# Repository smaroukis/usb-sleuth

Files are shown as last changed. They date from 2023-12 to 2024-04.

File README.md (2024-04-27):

See [this README](/README-downloading-firmware.md) for usage of the STM32CubeIDE to flash firmware on the device. 

## Overview

The device tests for continuity and internal resistors within various USB Cables and exposes some pins for multimeter testing. The project is a hardware fork of [aroerina/LimePulse](https://github.com/aroerina/LimePulse_USB_cable_checker/) that I decided to reverse engineer and write the firmware for.

A STM32C031K6T microcontroller is used for testing connection and orientation, powered by a CR2032 battery. Code is given using STM32 HAL libraries and the device can being programmed over SWD. 

KiCad and gerber files are provided for the board layout, as well as the library footprints for non-standard parts ordered from JLCPCB/LCSC. 
See the [BOM](/production/38-04-usb-tester_2023-12-18_rev1/bom.csv).

This USB cable tester has the "B" side on the right, and the "A" side on the left. Receptacles are given for the following:
- Type-C (both sides) 
- Type-C to A 
- Type-C to micro B (2.0)
- Type-C to mini B 

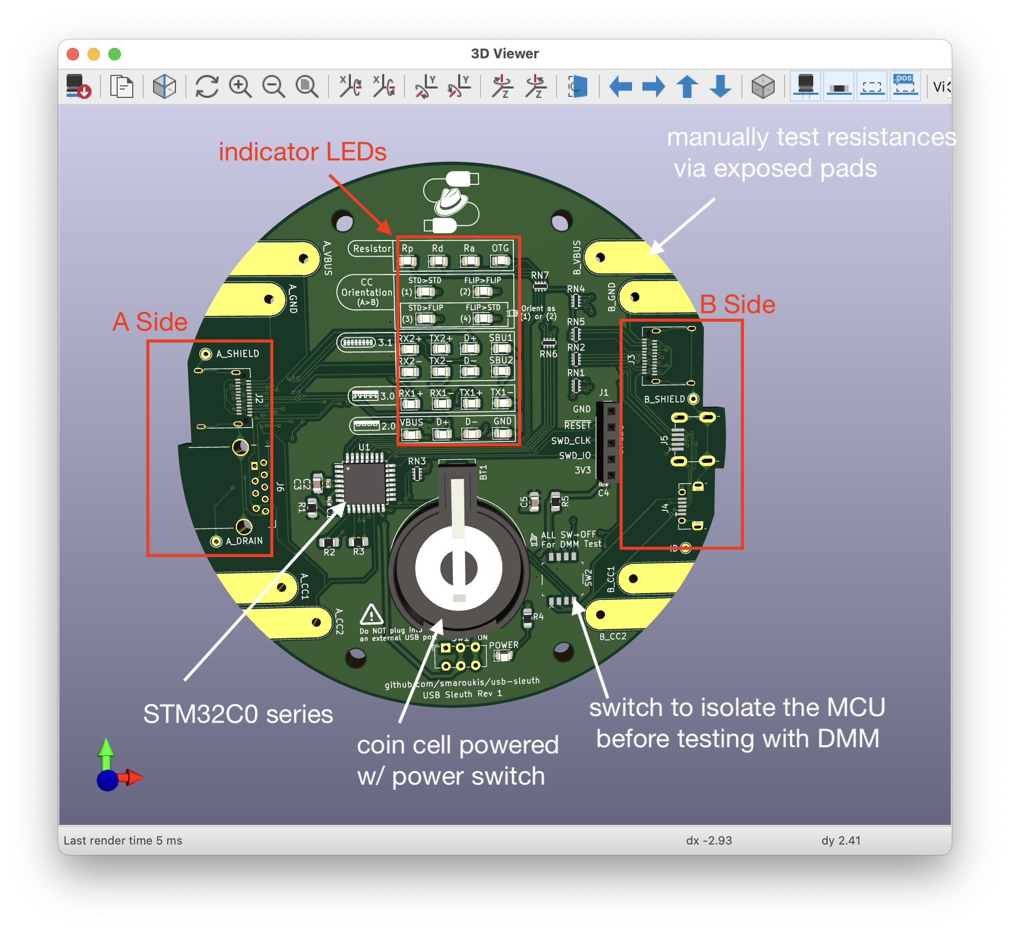
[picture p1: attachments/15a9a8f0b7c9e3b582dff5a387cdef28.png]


The device has some benefits over a simple continuity tester
- displays the as-plugged orientation of the 4 different possibilities of the USB-C to C cable
- detects pullup and pulldown resistors on the CC lines as required by the USB standard for legacy cables 
- identifies active cable with E marker (via the pulldown resistor present on VCONN)
- doesn't apply a +V to the Ground line/pin, instead it uses a MCU to test the presence of a connected ground wire
- exposes various pins to test cable and internal resistors manually with a DMM

## Example Tests

#### USB C-C Active Cable
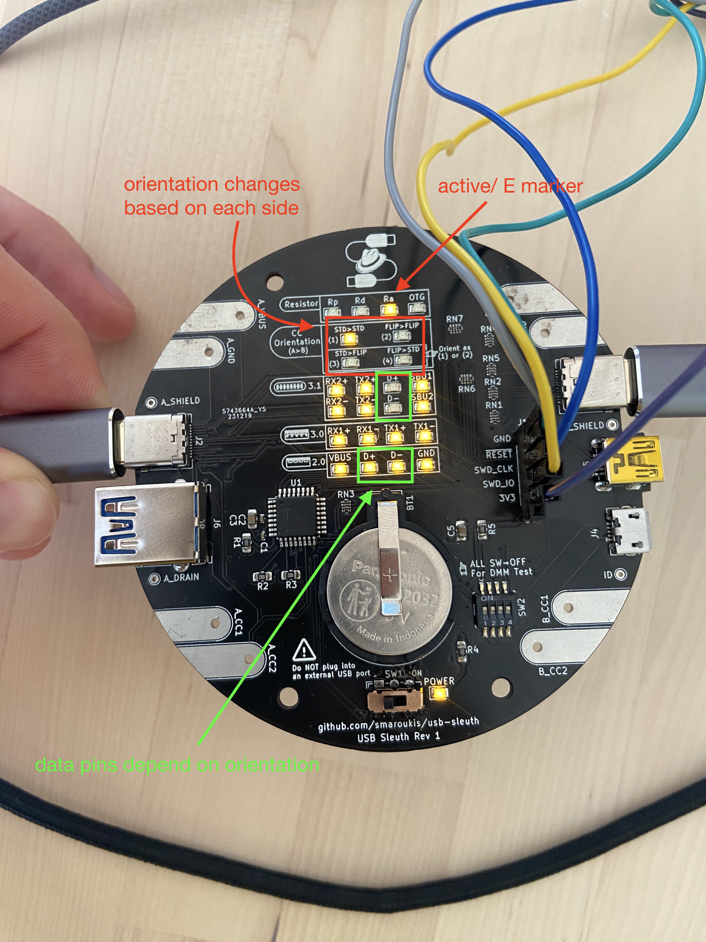
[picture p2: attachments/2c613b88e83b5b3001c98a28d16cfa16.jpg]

> Note in this test only one of the USB 2.0 Data pair LEDs will light up depending on the cable orientation, showing that the two pairs are not connected inside the cable (the pairs are also not connected on the PCB). The user must flip the orientation to test both data pairs. 
#### DMM Test of Internal Resistor

Testing the value of the pulldown resistor on an active cable by measuring between `B_CC2` and `B_GND` (should be between 800-1.2K Ohms).
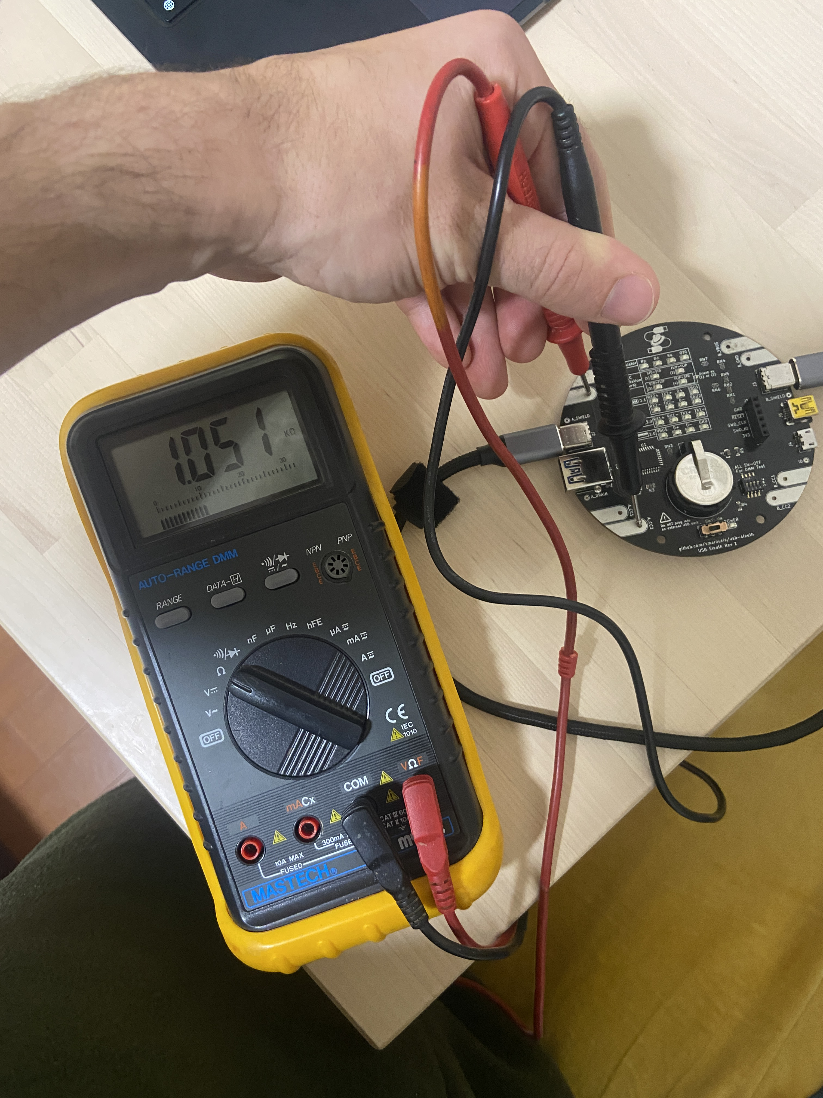
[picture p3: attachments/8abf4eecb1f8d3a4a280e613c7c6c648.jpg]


#### OTG Test

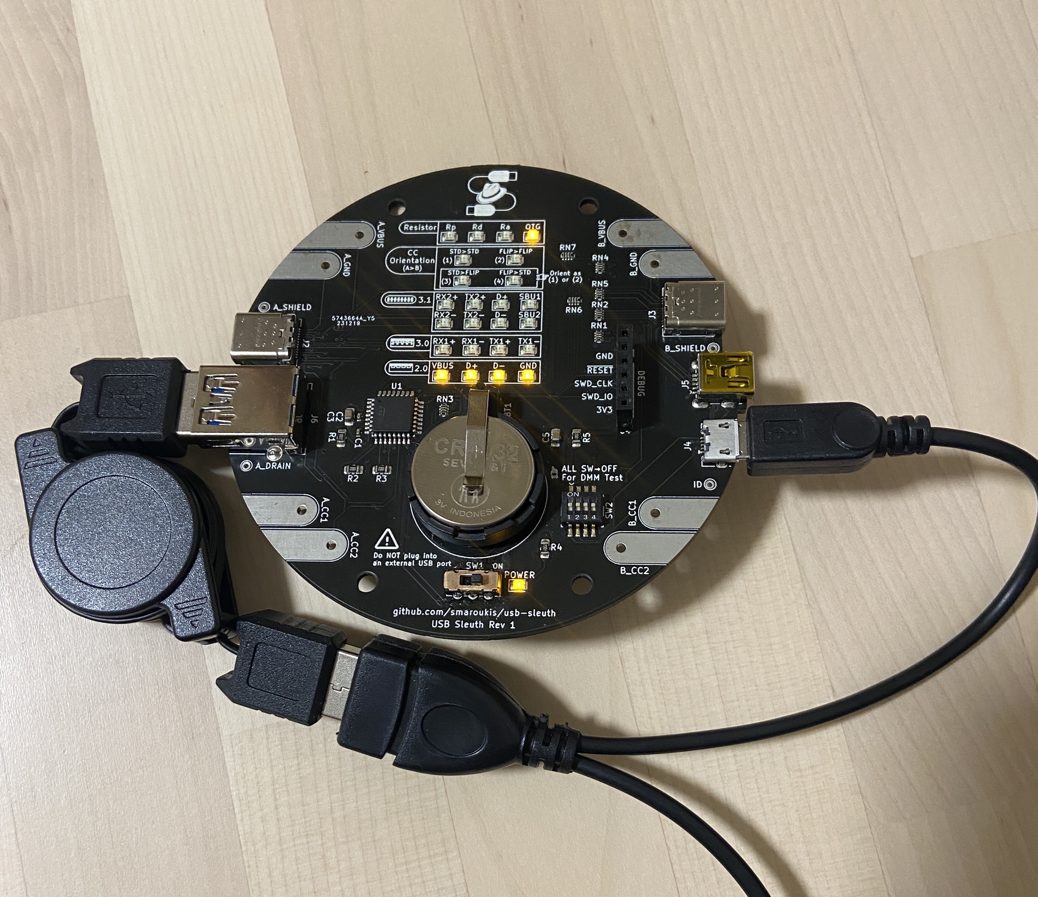
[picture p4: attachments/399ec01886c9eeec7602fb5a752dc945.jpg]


## General PCB Layout

Layout
- Various B side pins are biased to VBUS through pullup resistors. A side pins are either connected to ground through an LED, thus lighting up if the corresponding wire is continuous, or the pins are connected into the MCU for inputs. These pins that the MCU tests for are as follows:
- Ground (note all four GND pins are tied together)
- VBUS (note all four VBUS pins are tied together)
- CC1 to test for CC line and orientation
- CC2 to test for VCONN line and pull down resistor for active cables, as well as a flipped CC cable

> Note: Both A-side and B-side CC1 and CC2 pins are tapped off into corresponding control inputs to the MCU through a resistor, allowing for pulling the control pins high or low to sense the result on the opposite side.

Simplified layout of testing CC1 pin.
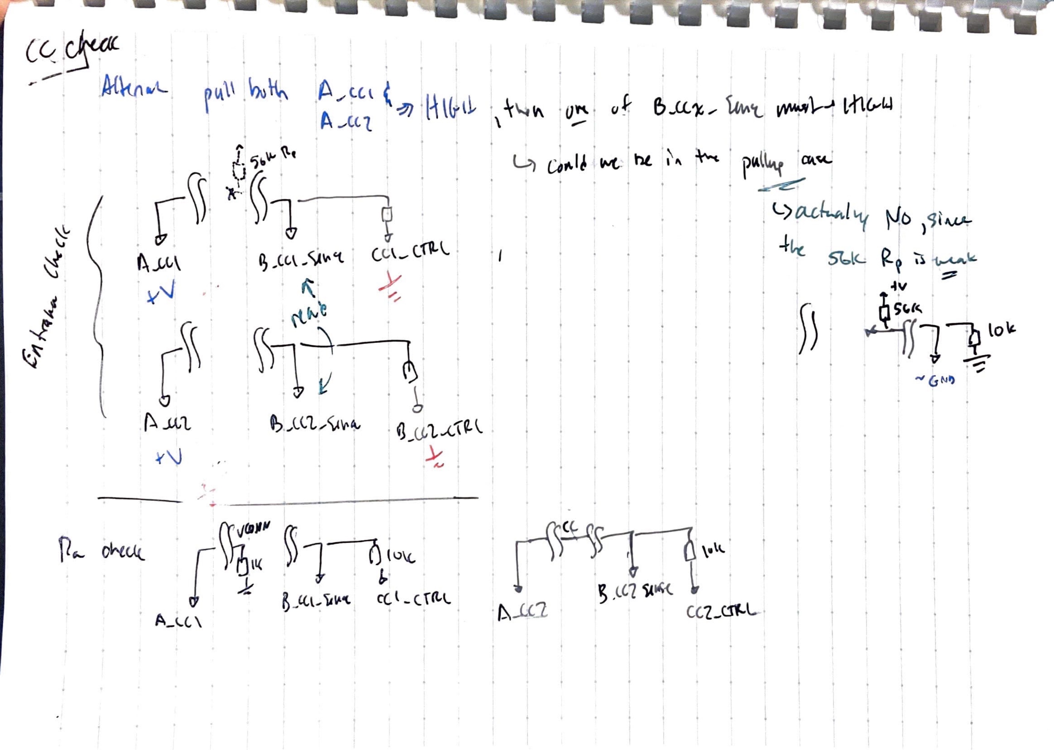
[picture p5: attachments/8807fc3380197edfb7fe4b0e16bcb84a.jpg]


## Programming and Reset

Programming is done via the Serial Wire Debug headers (labeled `DEBUG`) via an STLink debugger probe. 

The device can also be reset by shorting out the `nRESET` line to `GND` (pins 1 and 2 on the header).

> [!CAUTION]
> In the case where the debugger is providing power to the target, make sure the `POWER` switch is `OFF`.

> [!NOTE]
> For the `SWD` pins we need pullup or pulldown resistors on `SWDIO` and `SDCLK` respectively. These are provided internally by the STM32 MCU, but if there is an issue with the debugger try adding an external weak pulllup and pulldown (10K-100K).

# Description of Operation

## Sensing VBUS and GND 

> [!NOTE]
> `VBUS`: Pulled up on B-side to VDD via 2K, pulled down to ground at A-side MCU input sense pin via 10K. Sense pin reads high if VBUS line is continuous through the cable.
> `GND`: B-side receptacle ground pin connected to board ground, A-side receptacle pin is direct to input sense pin.

All VBUS pins are tied together and tested via a pulldown resistor on the MCU (similarly for GND pins).

Most B-side receptacle pins are pulled up to supply/VDD through resistors with exception for CC pins and Ground. B-side ground is connected to board ground through a DIP switch for isolation from the MCU ground if needed.
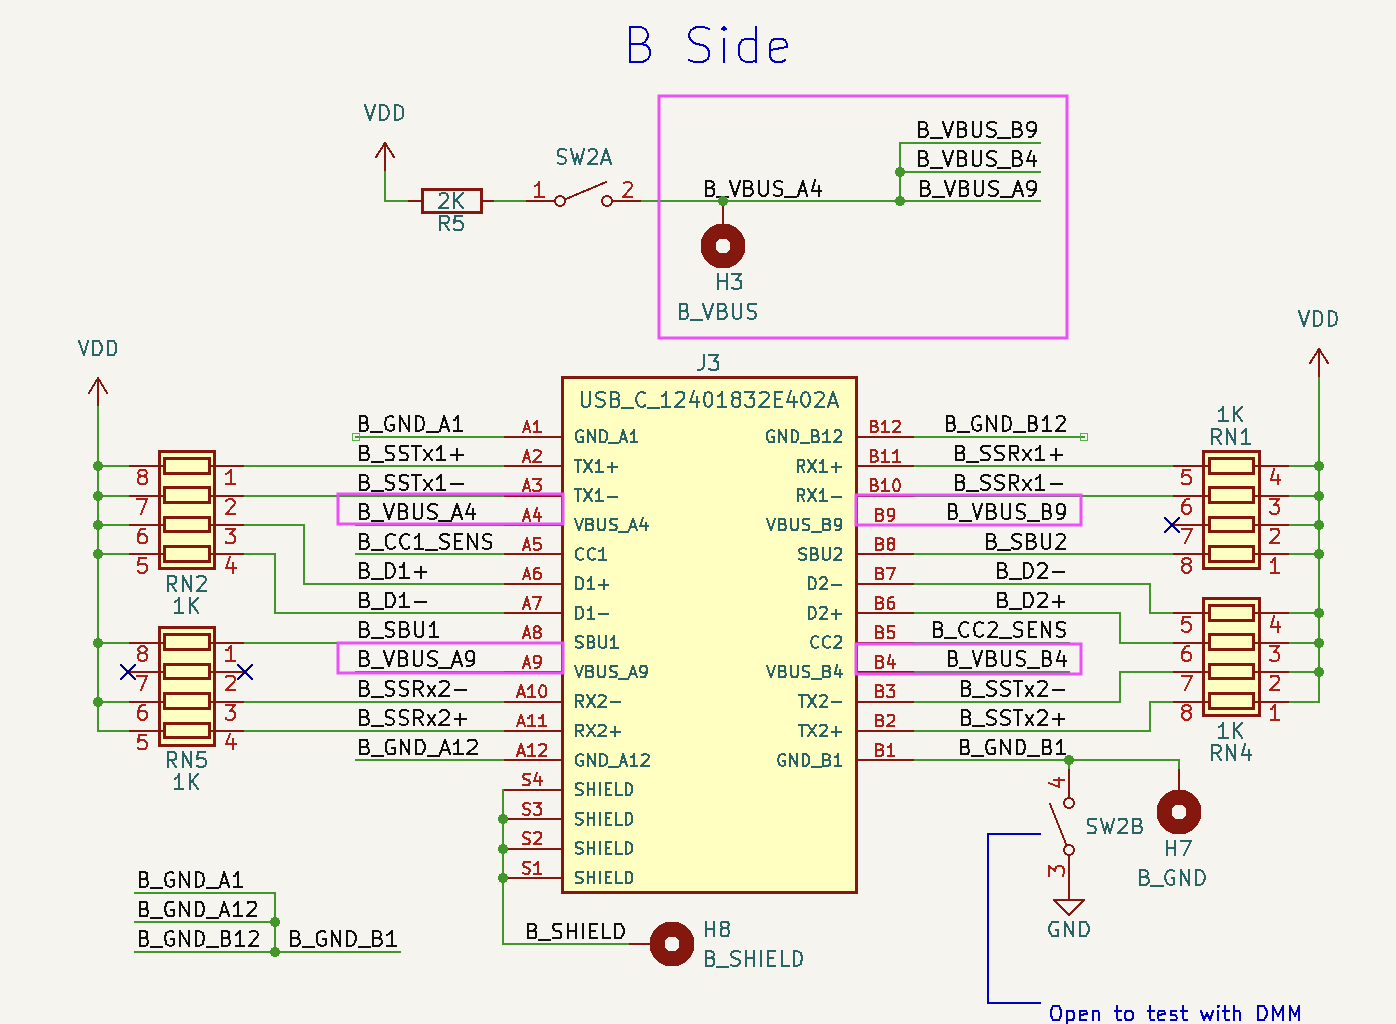
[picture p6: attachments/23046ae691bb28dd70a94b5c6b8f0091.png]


A-side receptacle pins are connected to the MCU input for sensing.
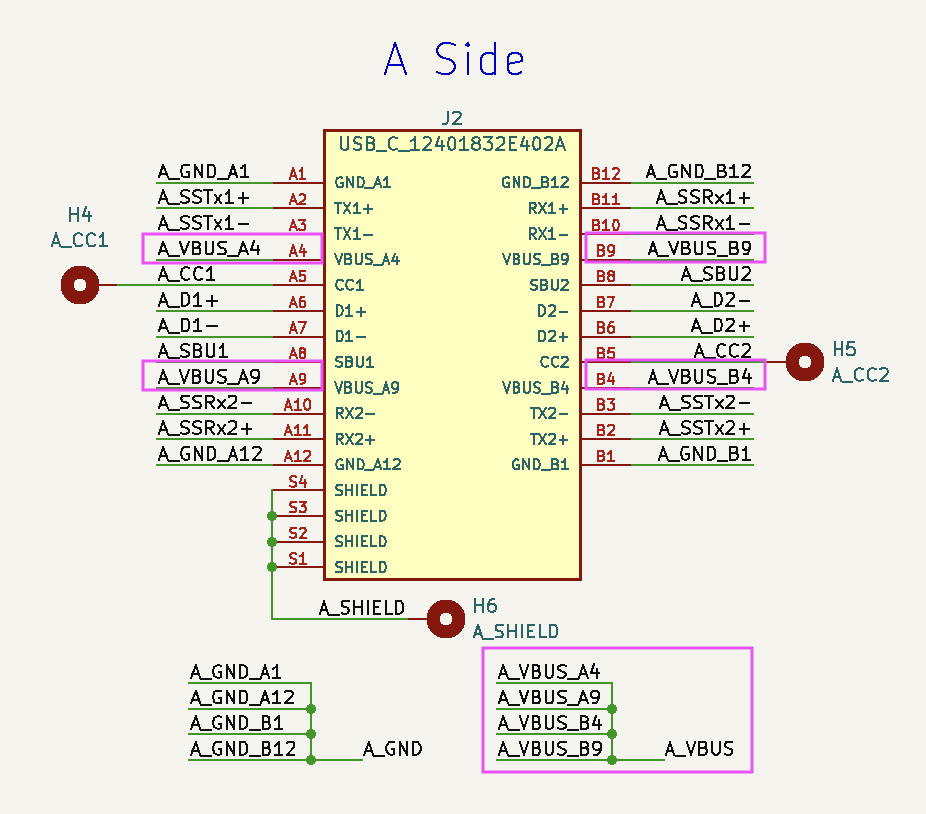
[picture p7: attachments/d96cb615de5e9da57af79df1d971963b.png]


`A_VBUS`/`A_GND` and connected to `VBUS_SENSE`/`GND_SENSE` inputs to the MCU through DIP switches for isolation from the MCU during DMM testing.

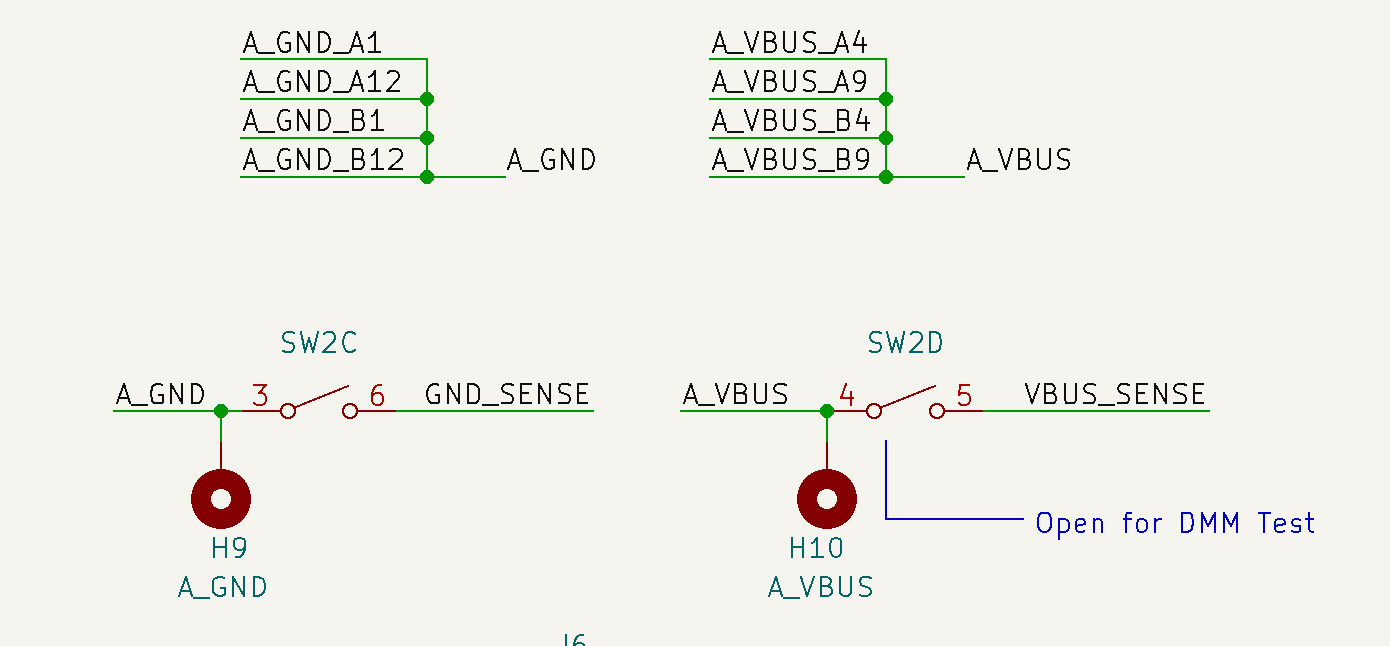
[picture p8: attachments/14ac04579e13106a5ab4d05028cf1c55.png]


`VBUS_SENSE` pin is an input to the MCU with a pull down resistor forming a voltage divider with the 2K VDD pulllup resistor. If the `VBUS` line is discontinuous, the pin reads `LOW`. If `VBUS` is continuous then the pin reads `VCC`x10/12, or digital `HIGH`. 

Indicator LEDs are driven by the MCU outputs `GND_LED` and `VBUS_LED`.

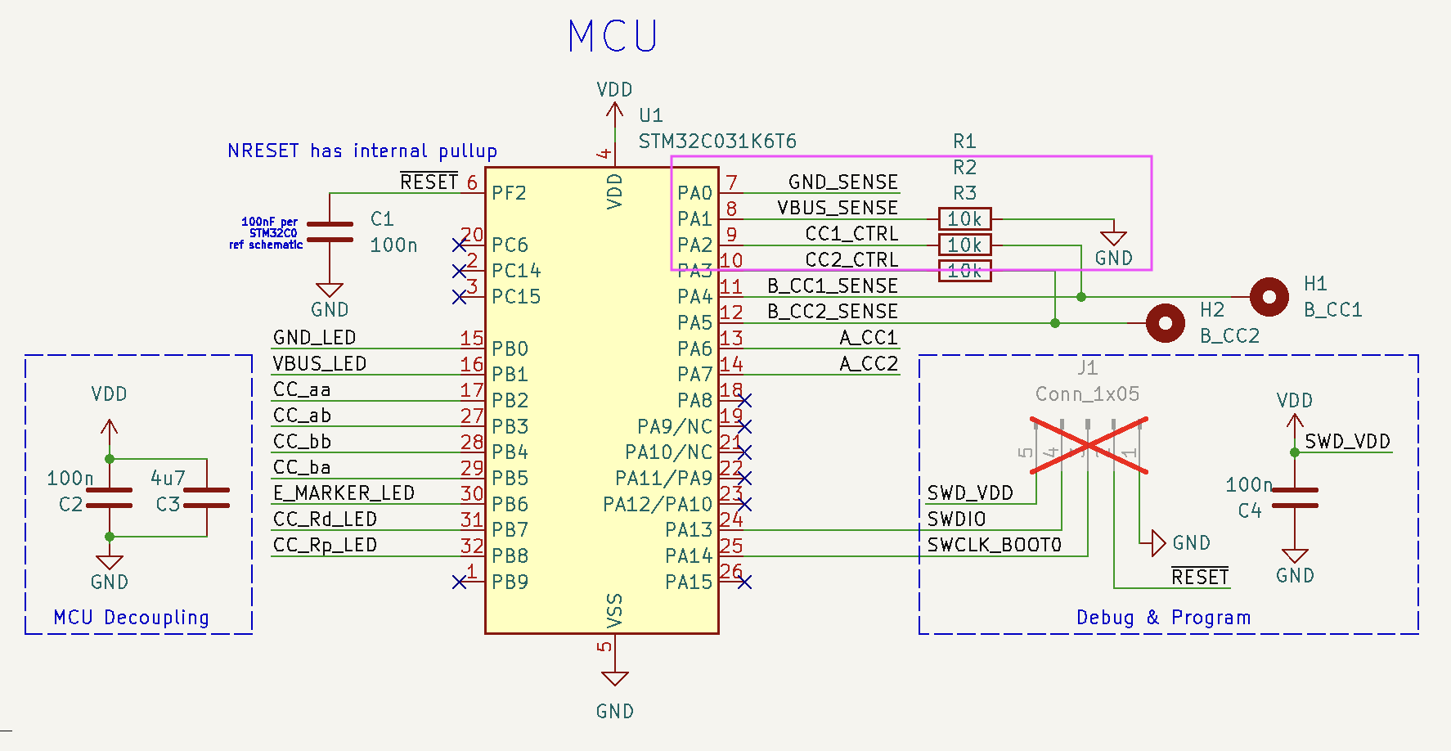
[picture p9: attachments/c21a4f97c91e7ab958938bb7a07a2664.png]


# MCU Testing Logic

### Orientation of CC Pin

Here is the type-C receptacle pinout 
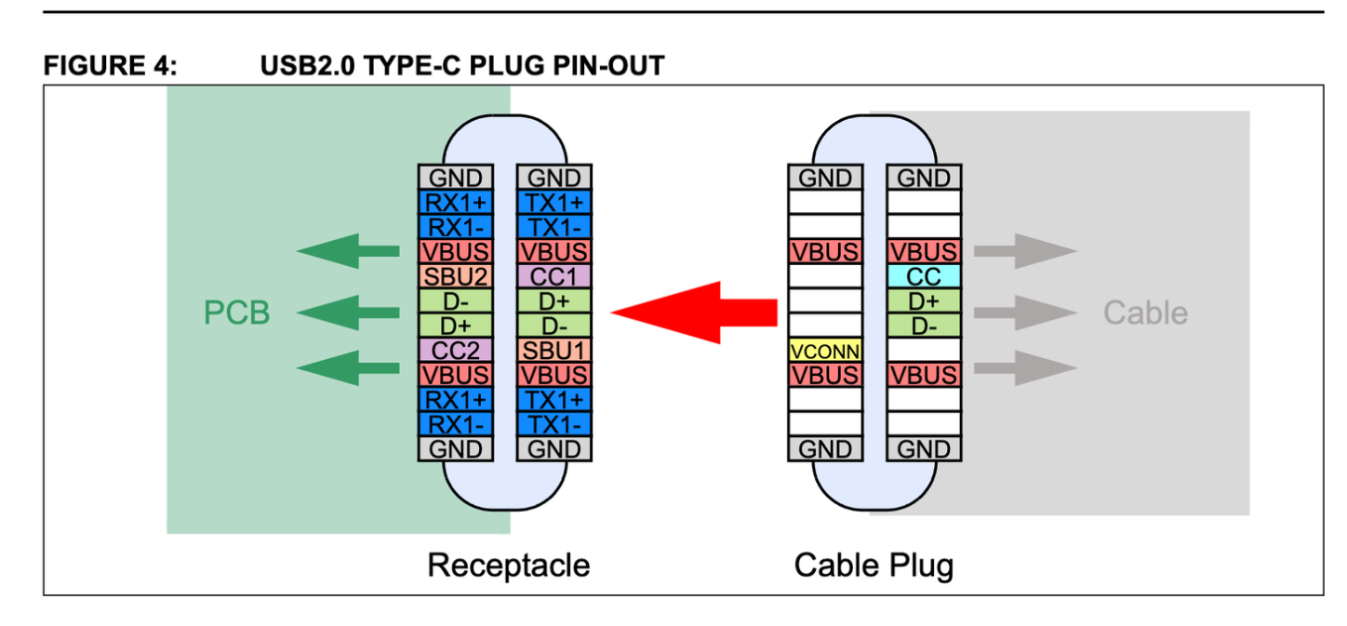
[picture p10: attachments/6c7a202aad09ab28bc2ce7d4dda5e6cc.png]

> Source: "USB 2.0 Type-C Plug Pin-Out" https://ww1.microchip.com/downloads/en/appnotes/00001953a.pdf

Possible orientations of USB-C Plug. 
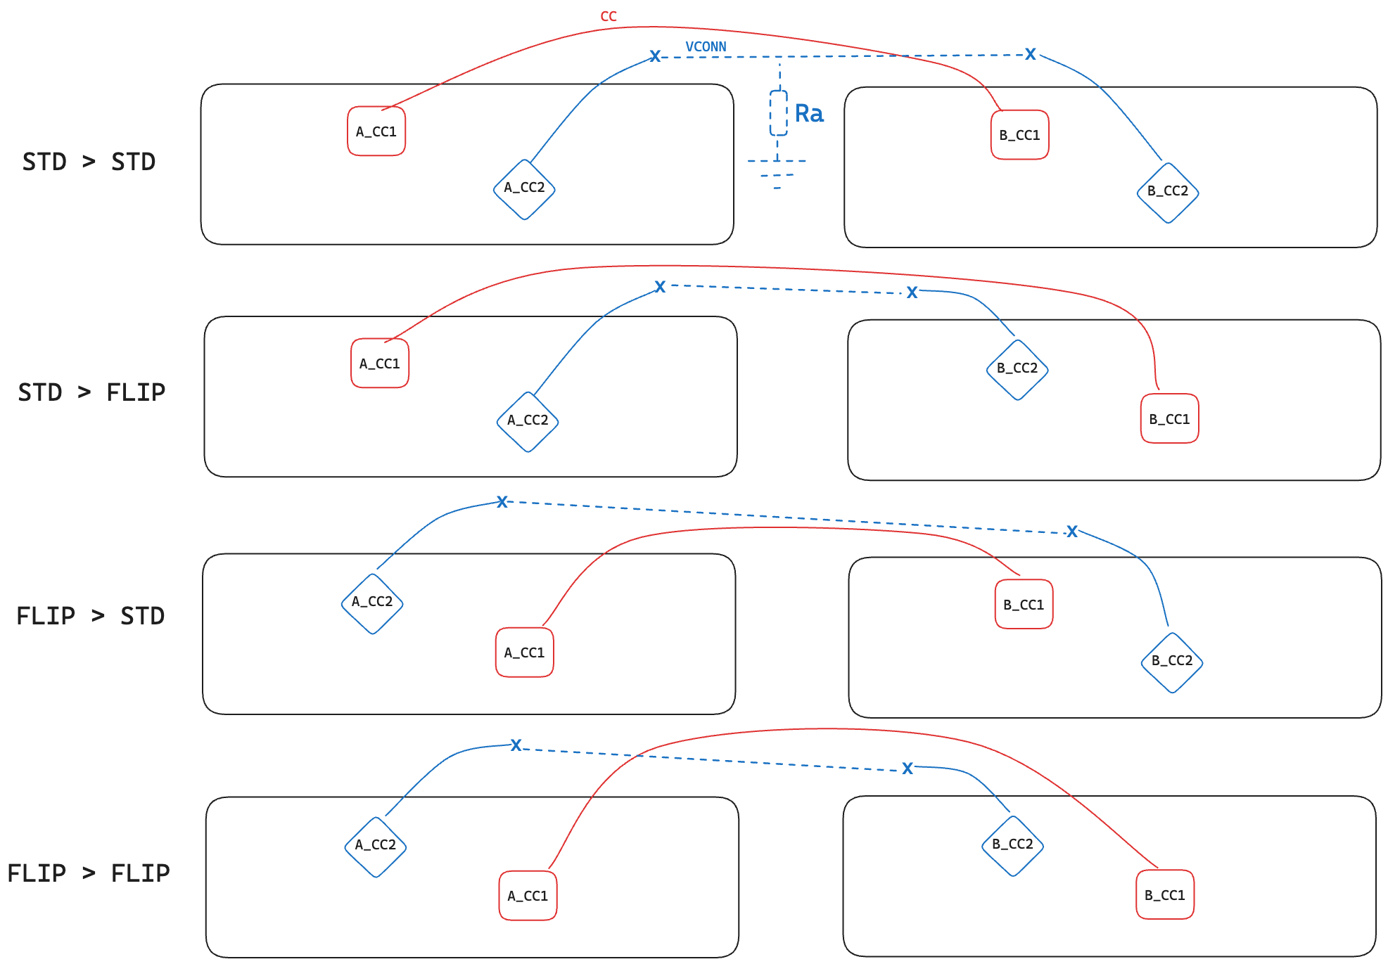
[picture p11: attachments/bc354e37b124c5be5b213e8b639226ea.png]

> Note Ra is for the active pulldown emarker, but don't take this "straight through" configuration literally as there are diodes preventing shorting of the pins.

Simplified PCB layout:


We can determine that a C-C type cable is connected by pulling both A_CC1 and A_CC2 HIGH and CCx_CTRL pins LOW, then looking for one of the B_CCx pins coming HIGH.

### MCU Testing of Ra on Emarker (Active) Cables

The pulldown (Ra, for "active") is nominally 800-1.2K. Connection is as follows:

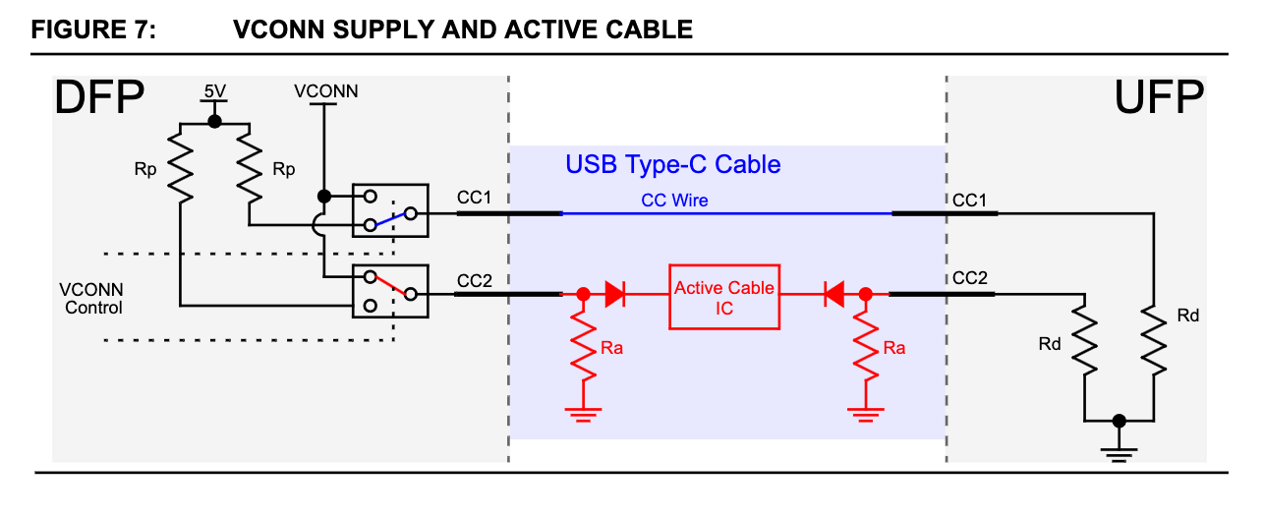
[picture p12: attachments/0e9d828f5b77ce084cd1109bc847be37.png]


We simply configure the `A_CC2` and `B_CC2` pins as `INPUT_PULLUP`s and test if these lines (the `VCONN` line) are pulled low (normally it is open), since the pulldown Ra is strong at ~1K.

## MCU Testing of Rp on Type-A to Type-C Cable

> [!NOTE]
> It is programmed to work for both USB-C plug orientations

Setup
1. `VBUS` is connected to `VCC` through a 2K resistor (ignored for the calculations below)
2. Write `CC1_CTRL` and `CC2_CTRL` → `LOW` (pulls `B_CCx` pin toward ground through 10K R)
3. Perform analog read of `B_CC1_sense` and `B_CC2_SENSE`
4. If the analog read is above a threshold, `RP_THRESH`, to account for ground noise, then the 56K Rp pullup exists. 

> [!TIP]
> An analog read is required since the internal Rp is weak enough such that it doesn't pull it all the way up to the digital `HIGH` threshold

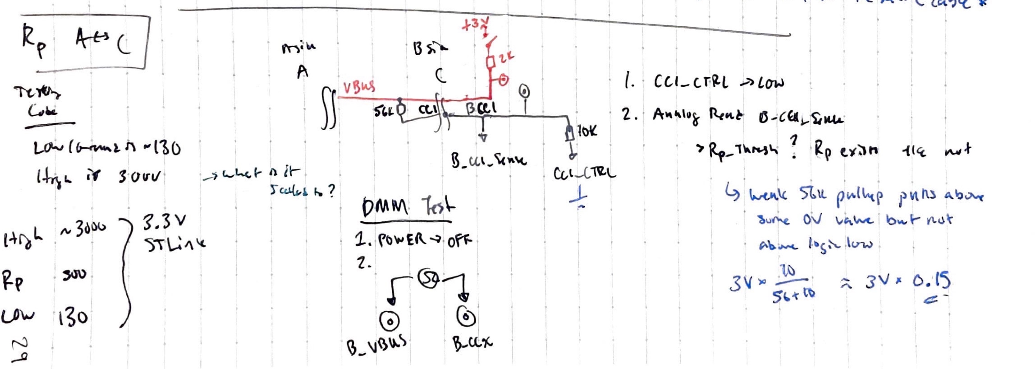
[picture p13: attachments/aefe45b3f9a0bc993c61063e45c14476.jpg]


## MCU Testing of Rd on Type-B to Type-C Cable

> Note this works for both CC configurations

1. Set `A_CC1` as `INPUT_PULLUP` (~50K internal pullup)
2. Read `A_CC1`, if pulled `LOW`, then it means that `Rp` is present (Rd = 5K which is much stronger than the 50K internal pullup)

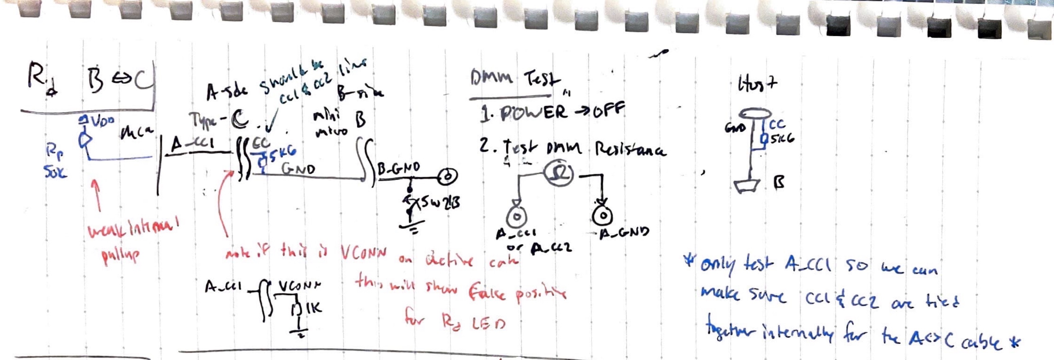
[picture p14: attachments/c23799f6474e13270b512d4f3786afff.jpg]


## Power Isolation For Testing

Isolation switches are provided to isolate the DMM from the MCU as it injects a test current to measure resistance, and also to allow us to measure the resistance of the cable itself (e.g. VBUS to GND). 

> Note during testing it was found that even with the switches closed the DMM measurements weren't affected.  

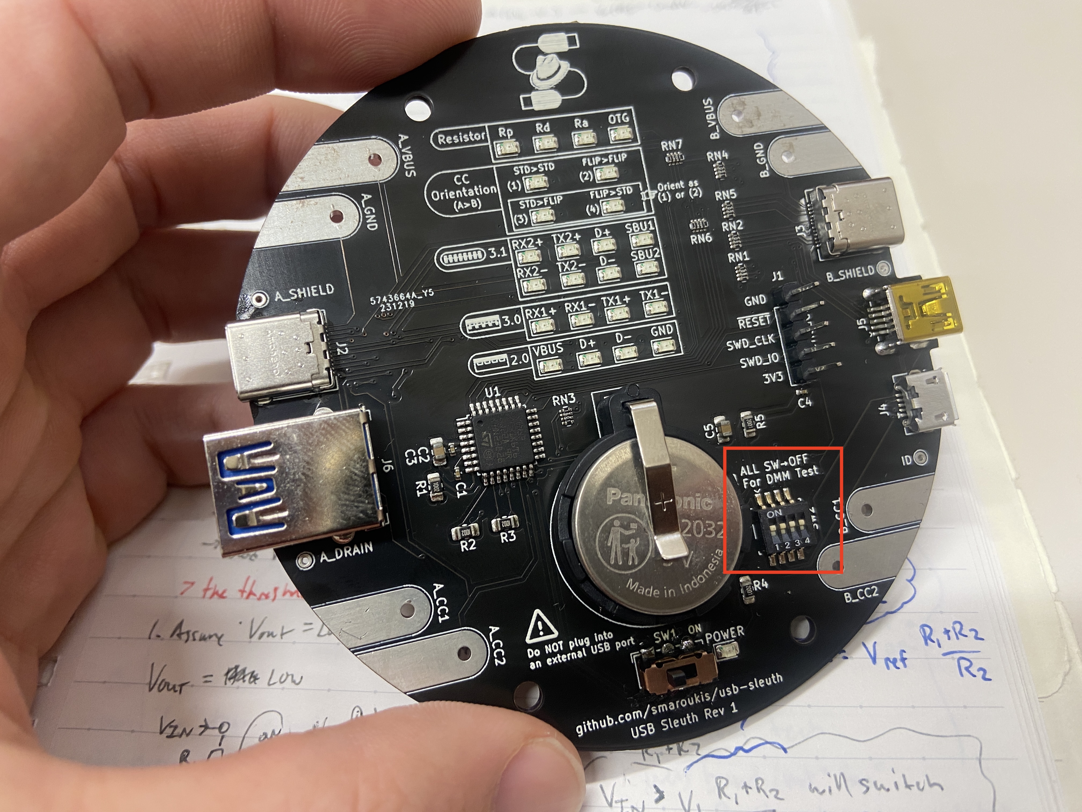
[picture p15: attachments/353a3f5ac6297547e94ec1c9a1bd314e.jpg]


In the schematic these are modeled as a multi-unit DIP switch:
- `SW2A`: Separates `VCC` from `VBUS`
- `SW2B`: Separates `B_GND` from `GND`
- `SW2C`: Separates `A_GND` from `A_GND_SENSE` (input to MCU)
- `SW2D`: Separates `A_VBUS` from `A_VBUS_SENSE` (input to MCU)

# DMM Testing

## DMM Testing of  Rp on CC line

> [!Caution]
> Verify the following:
> 1. USB cable is in the normal CC Orientation of `STD>STD` before proceeding (or note the configuration to choose the correct pad to test)
> 2. All DIP switches are in the OFF position
> 3. Power switch is in the OFF position

For the Type-A to C cable the USB standard specifies at 56K pullup resistor between `VBUS` and `CC` (since the A side is the host, CC pin needs to be pulled up for the B-side/peripheral to recognize A side as host). 

We can test the exact value of this resistor by using a DMM between `B_VBUS` and `B_CC1` testing pads.

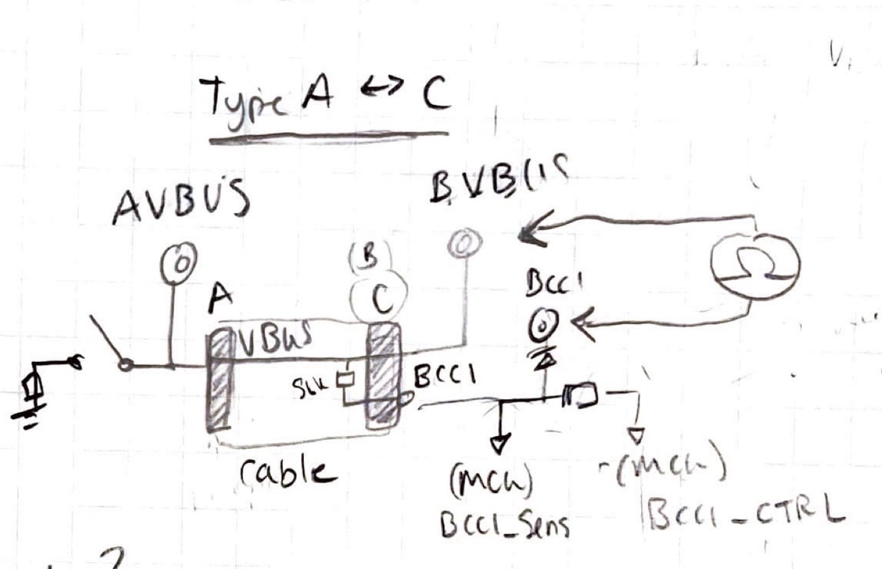
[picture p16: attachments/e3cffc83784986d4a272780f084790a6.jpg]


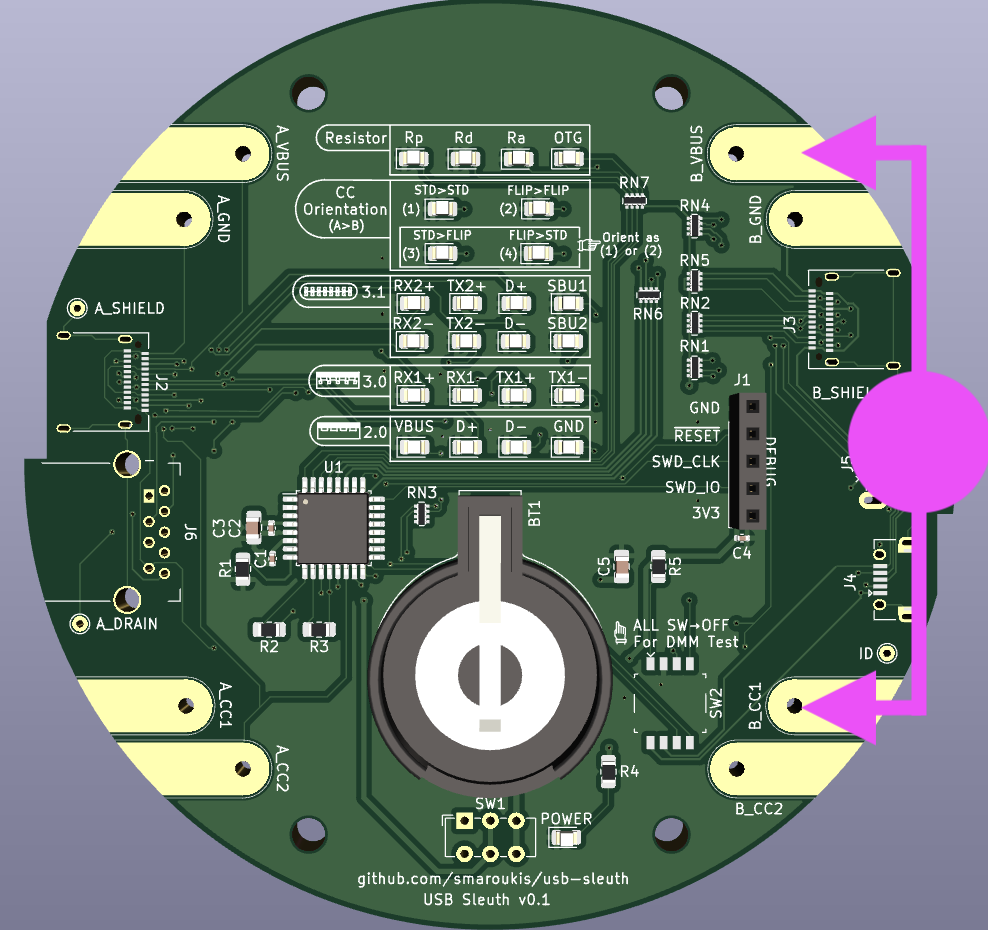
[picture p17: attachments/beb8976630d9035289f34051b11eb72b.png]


## DMM Testing of Rd

> [!Caution]
> Verify the following:
> 1. USB cable is in the normal CC Orientation of `STD>STD` before proceeding (or note the configuration to choose the correct pad to test)
> 2. All DIP switches are in the OFF position
> 3. Power switch is in the OFF position

For the Type-B to C cable the USB standard specifies at 5K6 pulldown resistor between `CC` and `GND` (since the B side is the peripheral, CC pin needs to be pulled down for the A-side/host to recognize B side as peripheral). 

We can test the exact value of this resistor by using a DMM between 
`A_GND` and `A_CC1` 

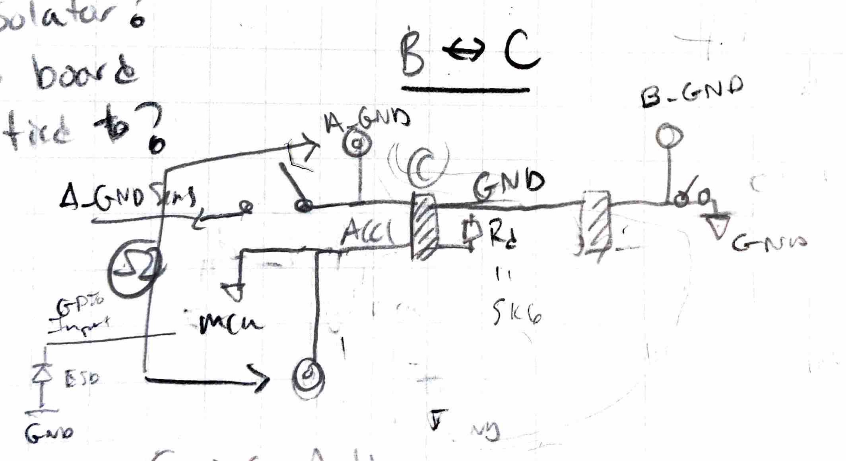
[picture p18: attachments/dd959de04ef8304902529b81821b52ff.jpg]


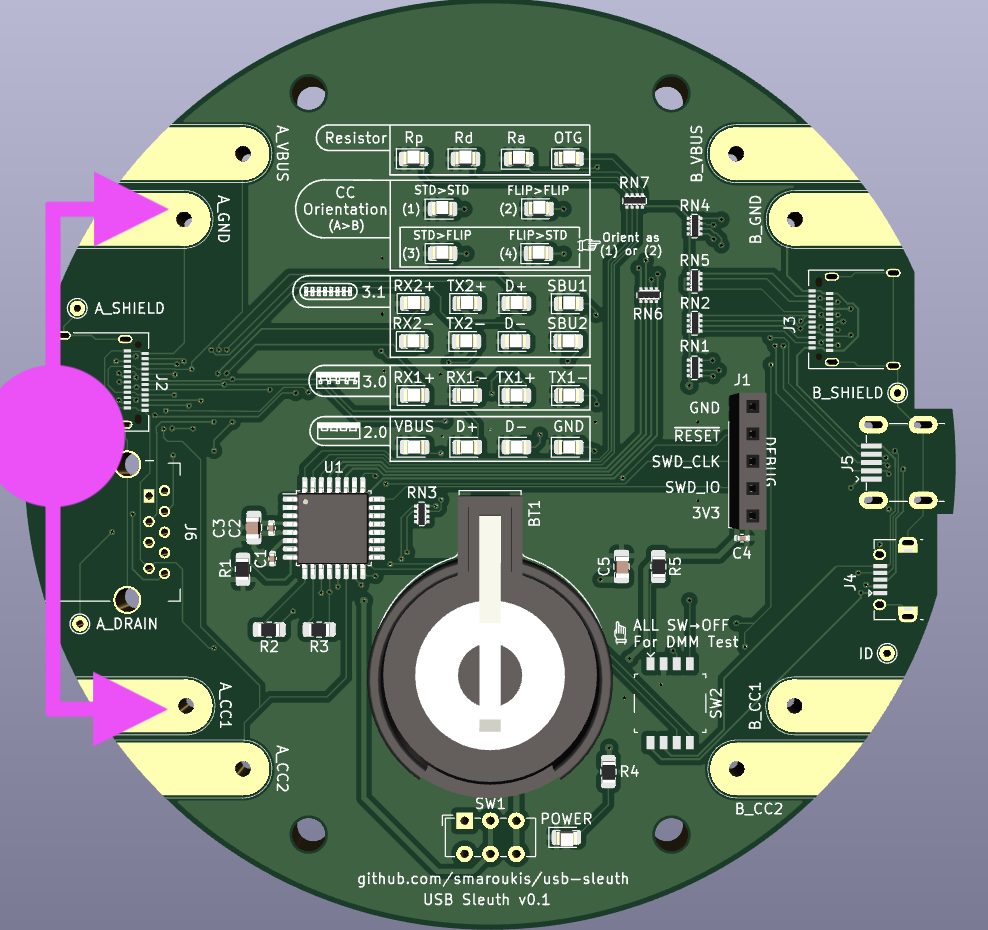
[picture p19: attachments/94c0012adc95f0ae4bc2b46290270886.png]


## DMM Testing of Ra

1. With device ON, make sure the CC orientation is `STD>STD`
2. Switch isolation switches to OFF
3. Switch power OFF
4. Place a DMM between `B_CC2` and `B_GND` since the Ra will be on the VCONN line.

# Shields and ID Pin

### Shields 
Shields are connected together and exposed to a through hole testing terminal. For this we can test with a multimeter. 

Note the shield and ground are connected inside the receptacle.

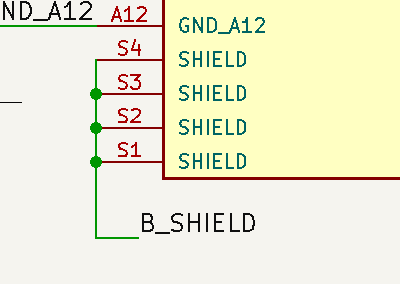
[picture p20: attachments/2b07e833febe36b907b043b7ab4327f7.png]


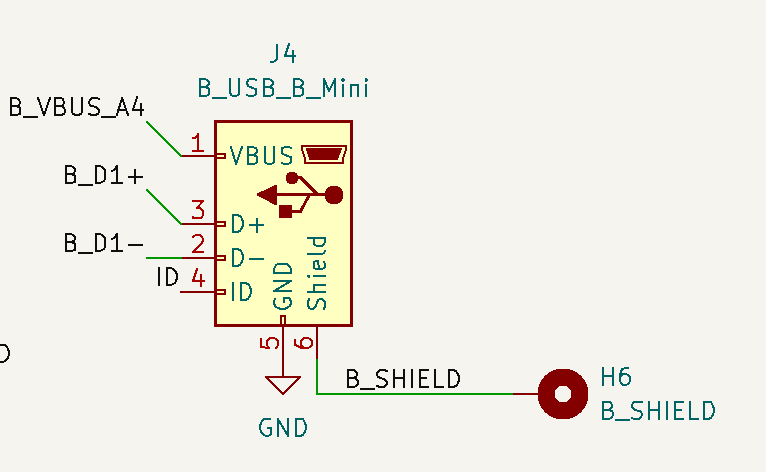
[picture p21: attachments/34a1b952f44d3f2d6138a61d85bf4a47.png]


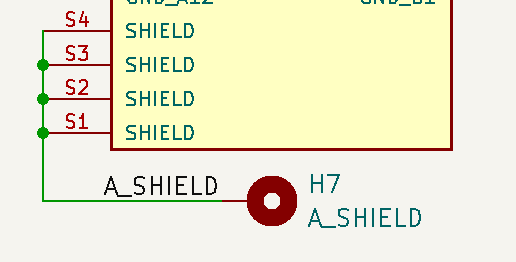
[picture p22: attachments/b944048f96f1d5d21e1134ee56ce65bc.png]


### ID (On The Go / OTG)

The OTG specification allows a USB device normally acting as a peripheral, to now act as a host (example use case: a tablet normally a peripheral, acting as a host can read from removable media on a flash drive)

For the OTG cable the A-plug side ties its ID pin to ground, and the B-plug side leaves it floating.  

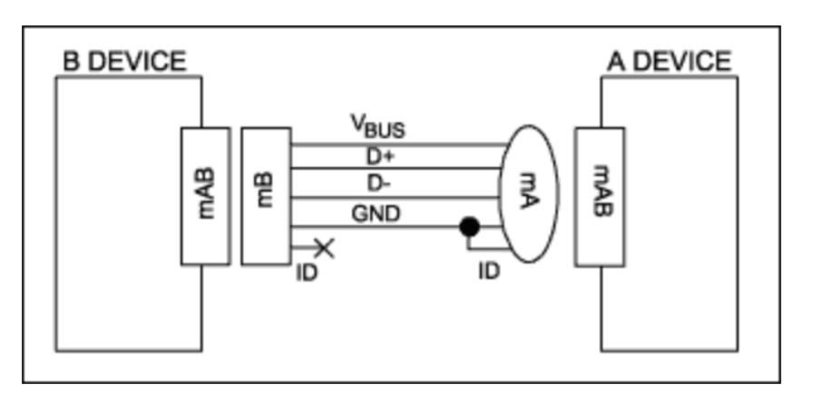
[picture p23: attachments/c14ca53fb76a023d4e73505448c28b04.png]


Since the ID pin is supposed to be tied to its ground pin within the plug, we just connect an LED between VDD → ID pin (=Ground pin) to test the connection.

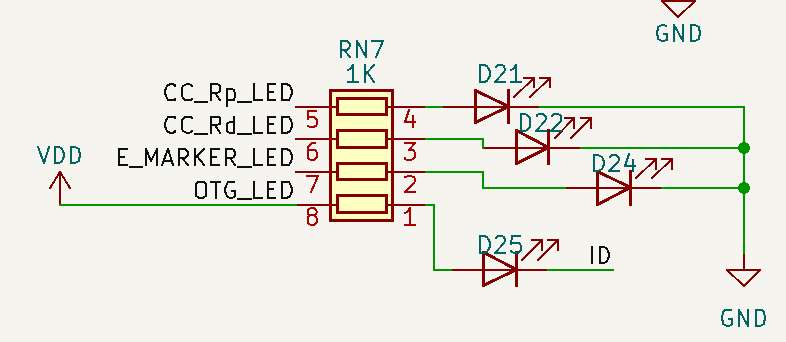
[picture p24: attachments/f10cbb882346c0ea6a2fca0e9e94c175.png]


> The ID pin is also brought out on an exposed pad.

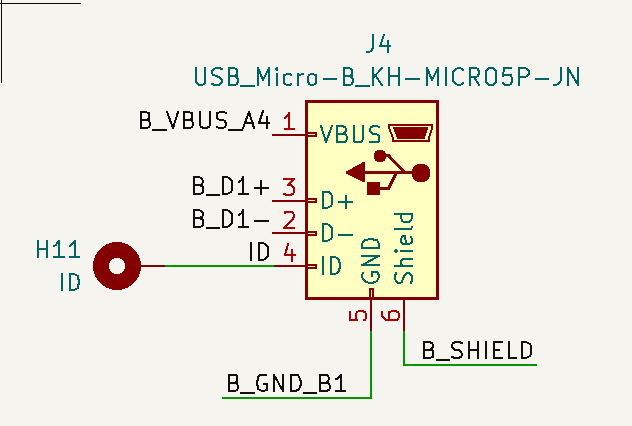
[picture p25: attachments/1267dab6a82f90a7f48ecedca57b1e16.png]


# FAQ

Only one set of the D+ and D- pins light up.
- The D1+/- and D2+/- pins are not connected together to allows the user to test both sets of pins independently (but requires the user to flip the USB-C side)

OTG Cable test doesn't work? 
- Make sure the test setup is as shown in the examples

> If the OTG cable has two male plugs, the data lines are not connected between the male ends, only from female → male 1 and female → male 2. The proper way to test will require the OTG adapter plus a normal USB cable. 

With one end plugged in, when I touch the other cable plug to the receptacle the GND (and sometimes Rd) LEDs light up.
- This happens because the tester first checks for VBUS=+Vsupply, and next checks for Ground=0V. If GND=0V it waits 300ms for the plug to "seat" before running through the other tests. But since the receptacle chassis and plug sheath are connected to GND, if you touch the plug to the receptacle it will read GND as 0V and proceed with the other tests. In the USB C<>B case, the Rd test will run if the CC pins aren't connected through on both sides, so it will also test once this contact is made.

# Notable Documentation

The USB-C Type Spec provides the Rp and Rd requirements for legacy cables.

For example, Type-C to 2.0 Type A:
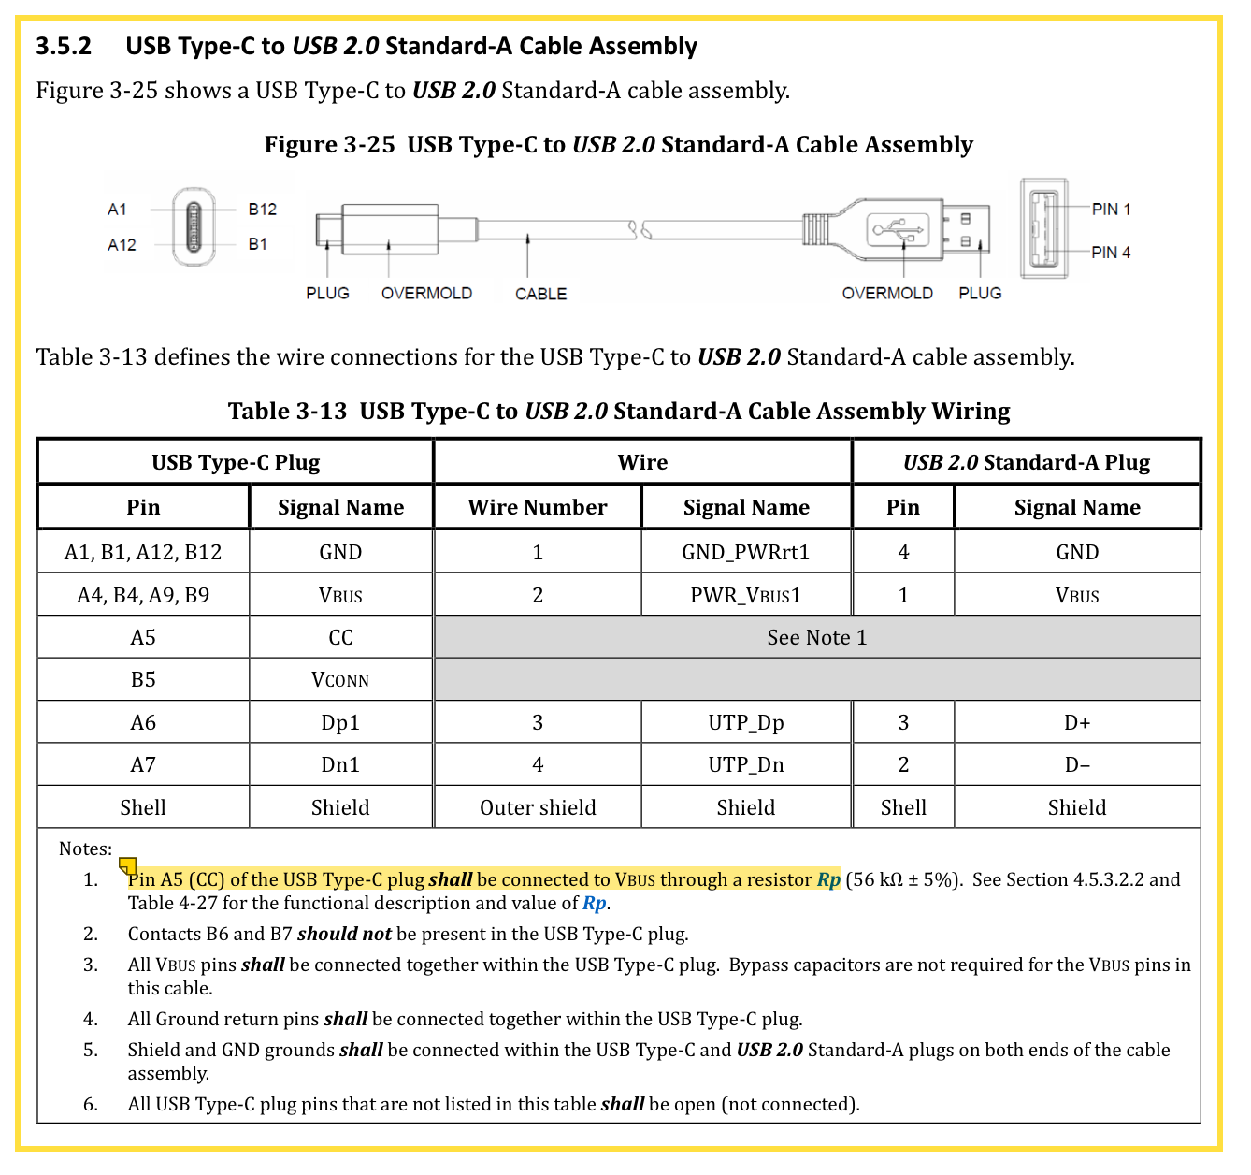
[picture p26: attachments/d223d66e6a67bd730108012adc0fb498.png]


USB Type-C Spec R2.3 - October 2023.pdf
> tl;dr any legacy cable assembly that **sources** power to a Type C connector must use the default 56K pullup (note this is for both 3.1 and 2.0 versions, since the power negotiation didn't come along until later)
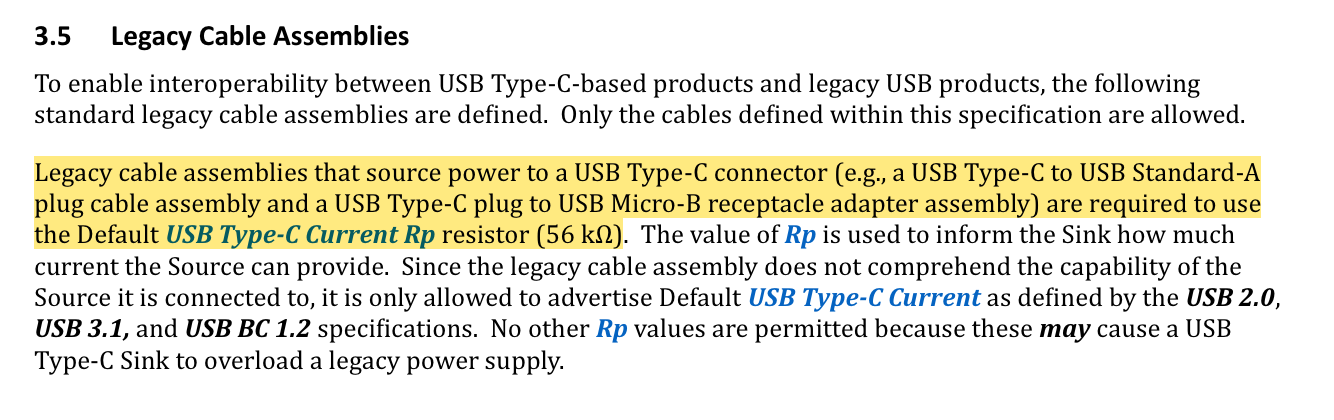
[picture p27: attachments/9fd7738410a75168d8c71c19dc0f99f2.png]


Note the A5 CC pin and the B5 VCONN pin are **not** connected internally. This means it is up to the hardware developer to implement orientation detection on the C-receptacle side. 

And here is for the Type-C to 2.0 Micro-B:
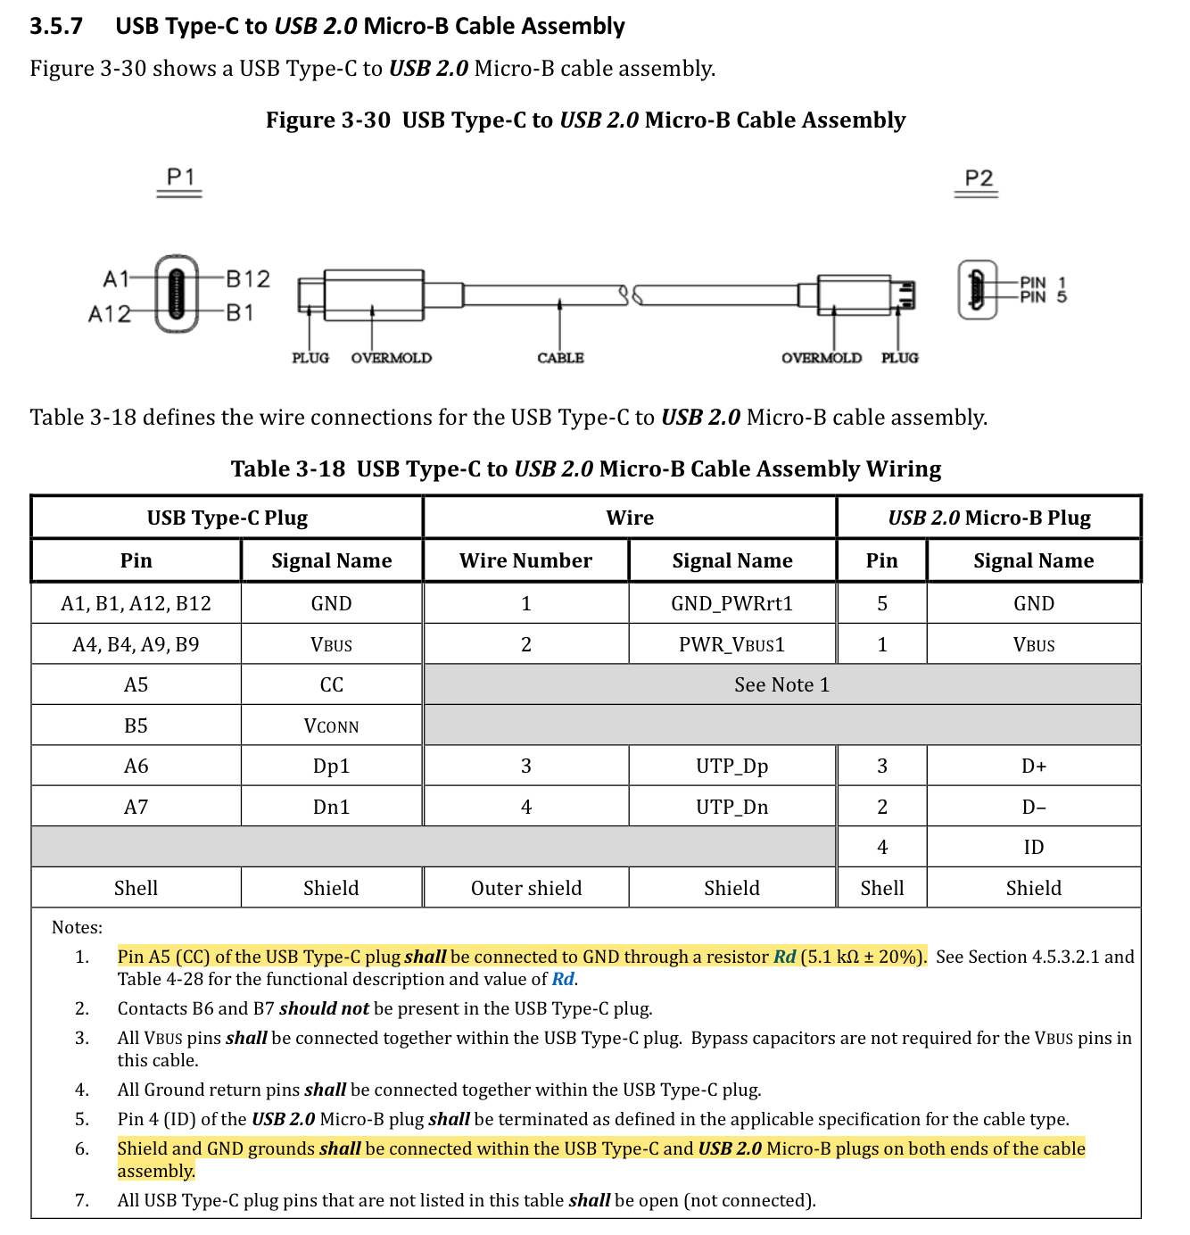
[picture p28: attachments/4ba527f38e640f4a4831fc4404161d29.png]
 ^dzdzs5

# Improvements
- USB C<> Micro/Mini B D+/D- LED pair is dependent on C side orientation - make it more user friendly by only lighting up the bottom 2.0 row
- Low power

# Attributions
**Icons**
- Fedora Hat by Sanjib Biswas from [vecteezy](https://www.vecteezy.com/png/24758745-fedora-hat-transparent-background) -  <a href="https://www.vecteezy.com/free-png/silhouette">Silhouette PNGs by Vecteezy</a>
- tip by Hothouse Design from <a href="https://thenounproject.com/browse/icons/term/tip/" target="_blank" title="tip Icons">Noun Project</a> (CC BY 3.0)
- Warning by Deylotus Creative Design from <a href="https://thenounproject.com/browse/icons/term/warning/" target="_blank" title="Warning Icons">Noun Project</a> (CC BY 3.0)

**Inspired By**
- https://github.com/petl/USB-C-cable-tester-C2C-caberQU
- https://github.com/alvarop/usb_c_cable_tester
- https://github.com/aroerina/LimePulse_USB_cable_checker/ - original inspiration for the design and functionality from its professional quality layout

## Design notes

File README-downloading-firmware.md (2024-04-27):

First, make sure the project has these files otherwise STM32CubeIDE won't have the correct build and debug settings (you won't even be able to build):
- .cproject
- .mxproject
- .project
- .ioc file
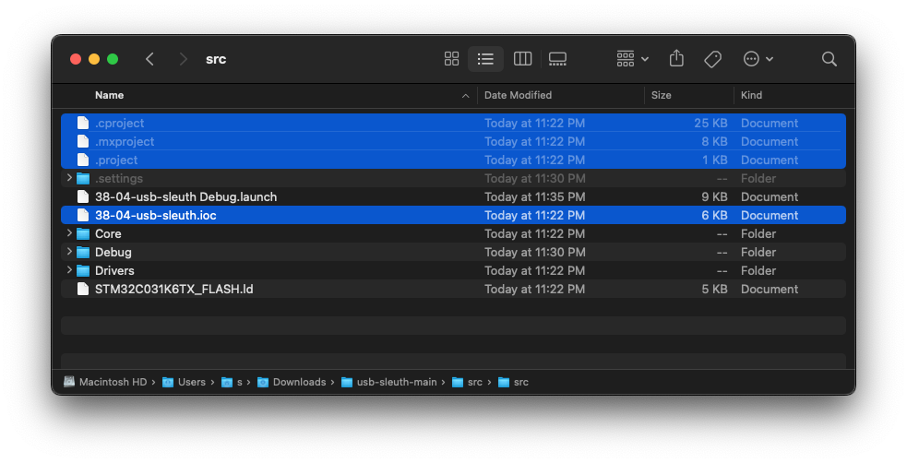
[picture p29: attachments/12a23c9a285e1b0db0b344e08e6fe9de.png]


Then import the project as  `File > Import > Projects from Folder or Archive`

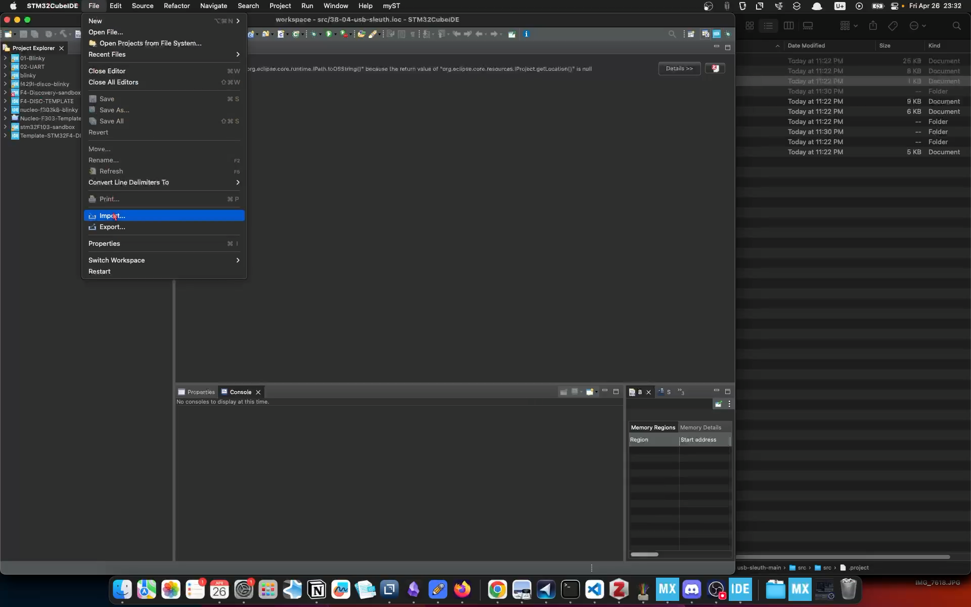
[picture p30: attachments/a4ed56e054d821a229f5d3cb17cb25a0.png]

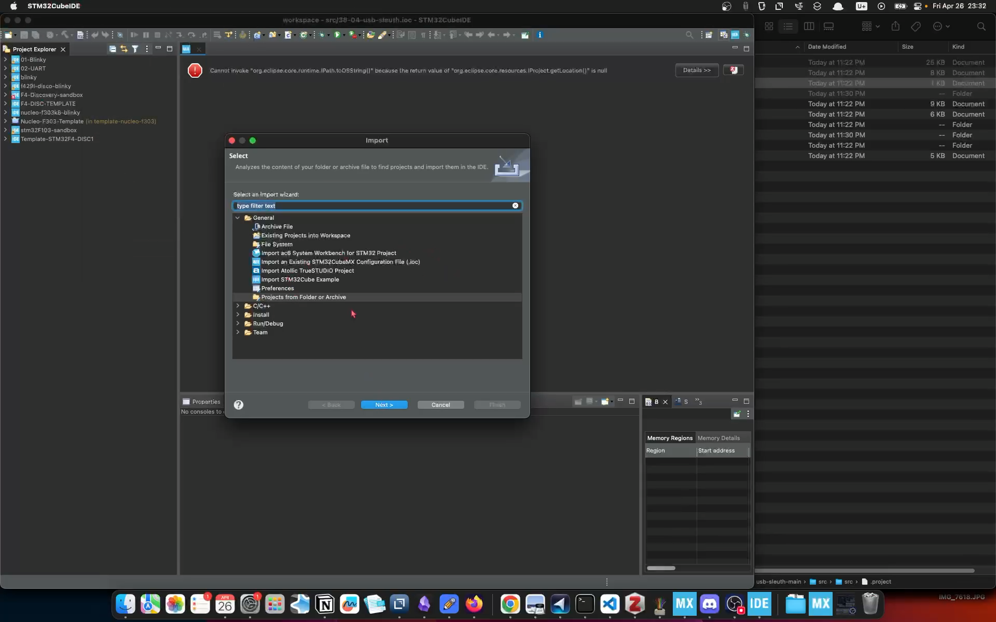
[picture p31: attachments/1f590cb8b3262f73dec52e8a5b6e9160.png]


Select the project root and make sure the following dialogue has the checkbox checked in the form field for the project and click `Finish` to import the project

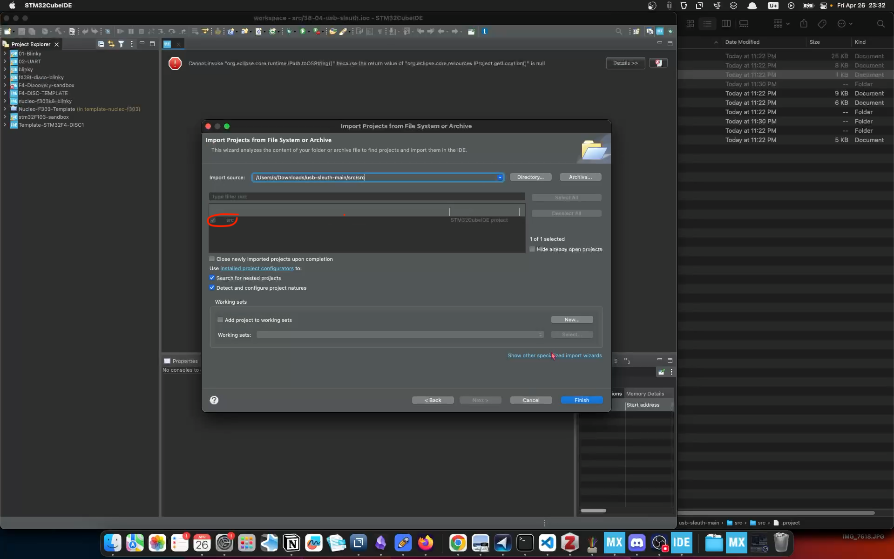
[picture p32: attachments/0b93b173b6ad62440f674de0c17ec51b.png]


> [!NOTE] If this checkbox is not checked it won't import the project. It could be that the CubeIDE thinks you already have imported the project into your workspace, so you need to delete the project from your workspace (or open a new workspace), and refresh/clean the workspace, then you should be able to import again.

You should now see the project in the sidebar as e.g. `38-04-usb-sleuth (in src)`

Click on the project and then see if you can build it:
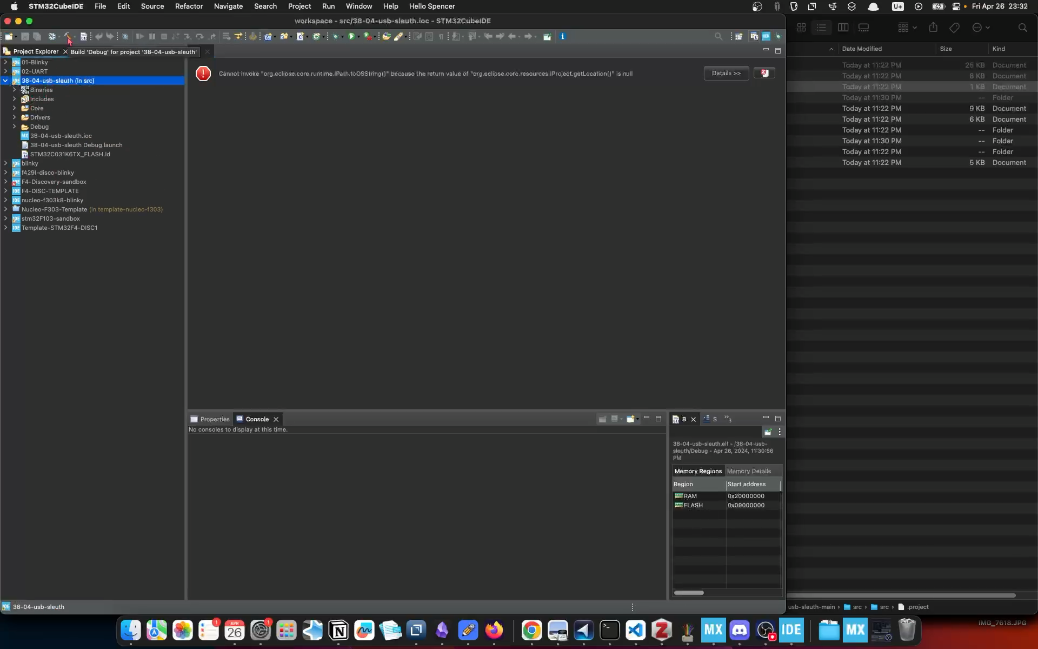
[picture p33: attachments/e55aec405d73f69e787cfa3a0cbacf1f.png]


Note: Build issues could be missing driver dependencies or other source/header files missing, or a bad configuration of the Includes paths. HAL drivers should be in `src/Drivers`.

To flash the firmware right click on the project and go to `Run As > STM32 C/C++ Application`

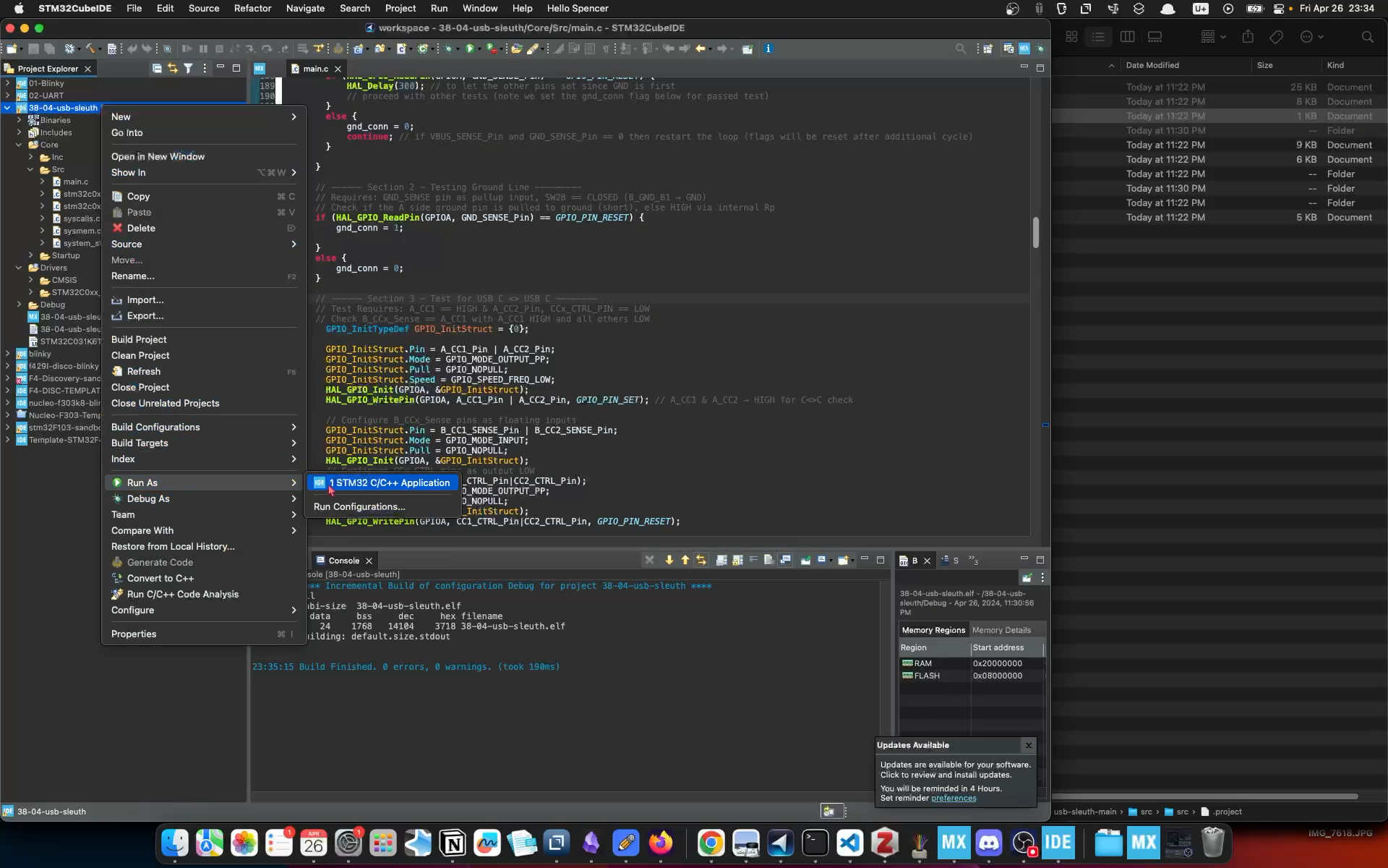
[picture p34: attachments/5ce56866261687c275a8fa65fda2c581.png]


Make sure the console shows the correct project is being build and run. It is easy to accidentally select the wrong project. 

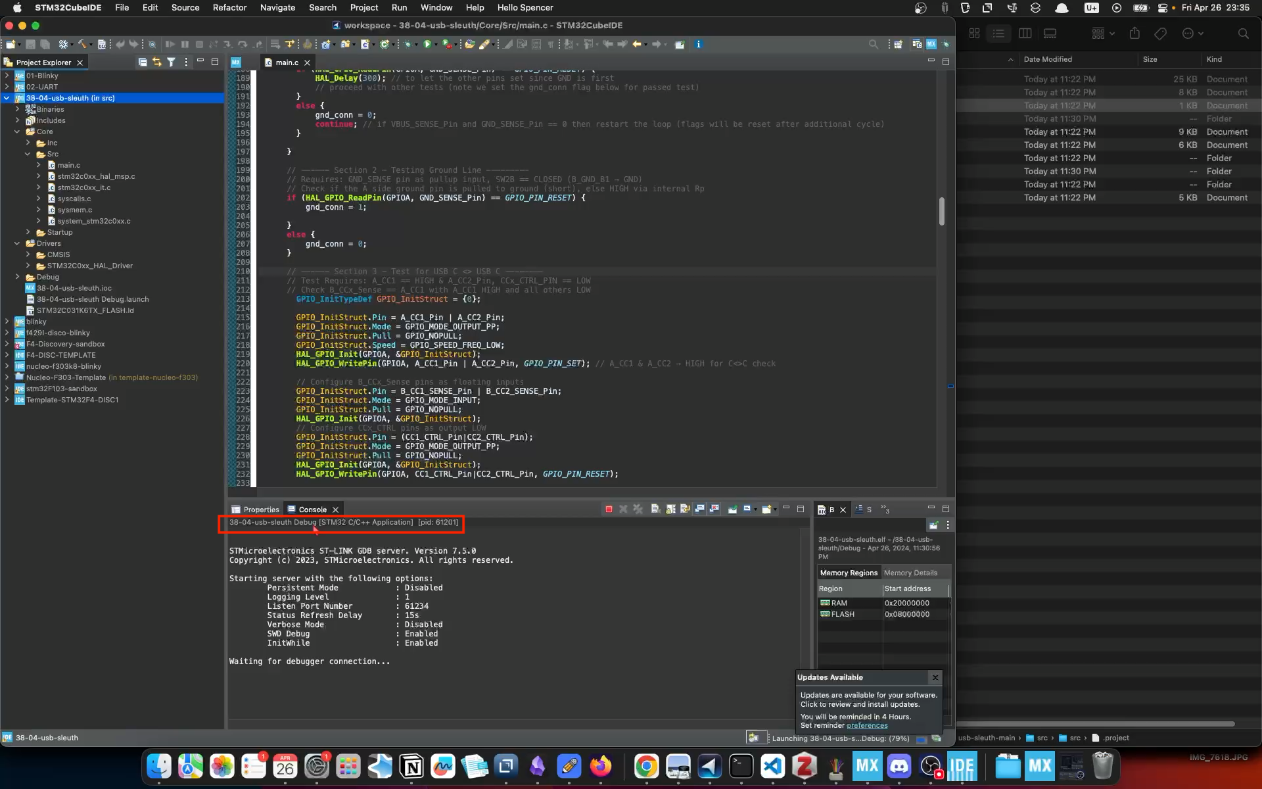
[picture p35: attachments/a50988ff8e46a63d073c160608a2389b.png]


Verify download is complete - you should now have a flashed device!
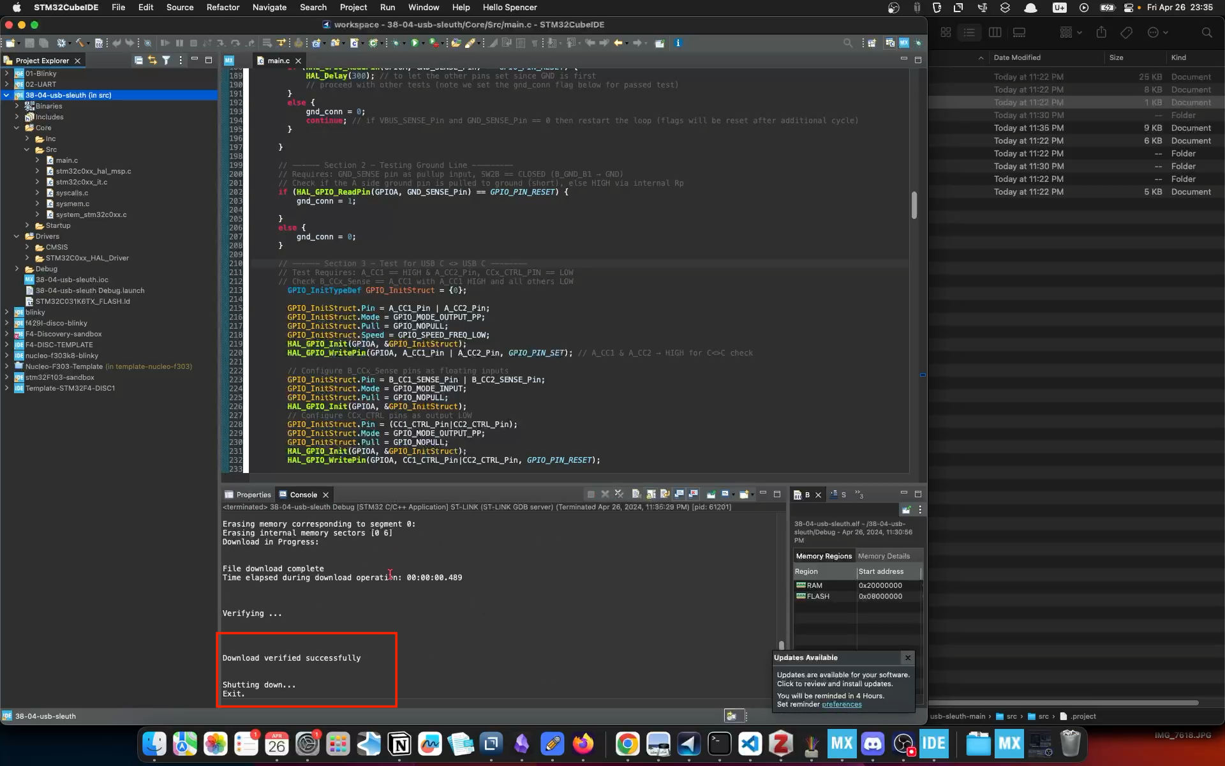
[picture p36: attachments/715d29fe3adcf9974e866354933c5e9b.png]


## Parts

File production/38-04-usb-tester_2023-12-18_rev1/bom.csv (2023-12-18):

Designator | Footprint | Quantity | Value | LCSC Part #
C1, C2, C4 | 402 | 3 | 100n | C1525
C3 | 805 | 1 | 4u7 | C1779
C5 | 805 | 1 | 1uF | C28323
D1, D10, D11, D12, D13, D14, D15, D16, D17, D18, D19, D2, D20, D21, D22, D23, D24, D25, D3, D4, D5, D6, D7, D8, D9 | 805 | 25 | YLW | C2296
J2, J3 | USB_C_Receptacle_Amphenol_12401832E402A | 2 | USB_C_12401832E402A | C464604
J4 | USB_Micro-B_Kinghelm-KH-MICRO5P-JN | 1 | USB_Micro-B_KH-MICRO5P-JN | C962222
J5 | USB_Mini-B_Korean-Hroparts_U-M-M5DD-W-1_SMD-5-4MP | 1 | USB_Mini-B_U-M-M5DD-W-1 | C145778
J6 | USB3_A_Hong-Cheng_HC-USB3.0-L168-WP_THT-9-2MP_P2.0mm | 1 | USB3_A_HC-USB3.0-L168-WP | C7501850
R1, R2, R3 | 805 | 3 | 10k | C17414
R4, R5 | 805 | 2 | 2K | C17604
RN1, RN2, RN3, RN4, RN5, RN6, RN7 | R_Array_Concave_4x0402 | 7 | 1K6 | C728711
SW2 | SW-DIP-4P_P1.27mm_SMD-2x4 | 1 | ZX-1.27BM-4PSMD | C5160896
U1 | LQFP-32_7x7mm_P0.8mm | 1 | STM32C031K6T6 | C5456169

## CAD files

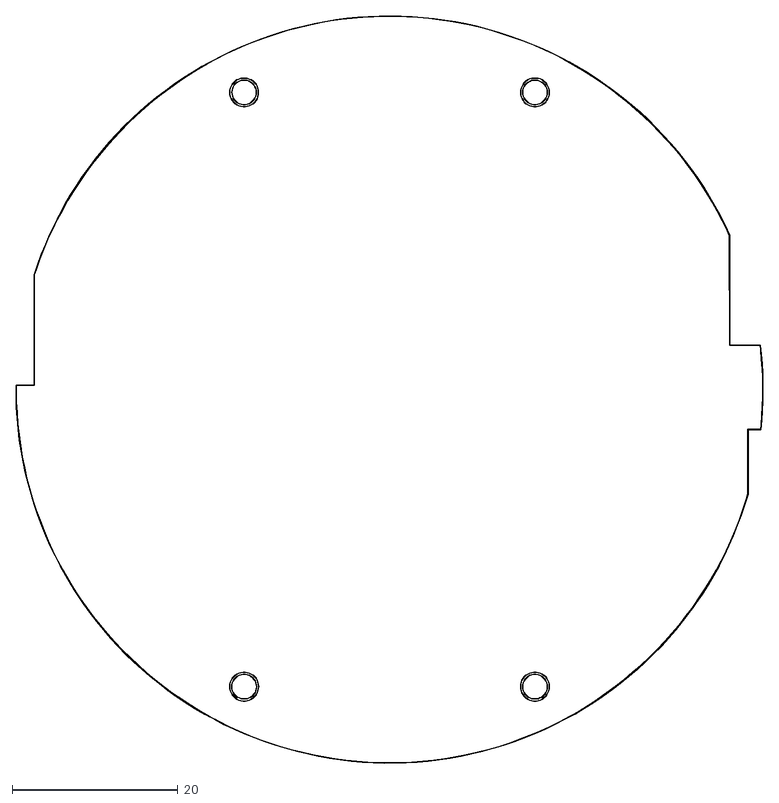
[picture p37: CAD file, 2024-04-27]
production/38-04-usb-sleuth-Edge_Cuts.dxf
90.0 x 90.0

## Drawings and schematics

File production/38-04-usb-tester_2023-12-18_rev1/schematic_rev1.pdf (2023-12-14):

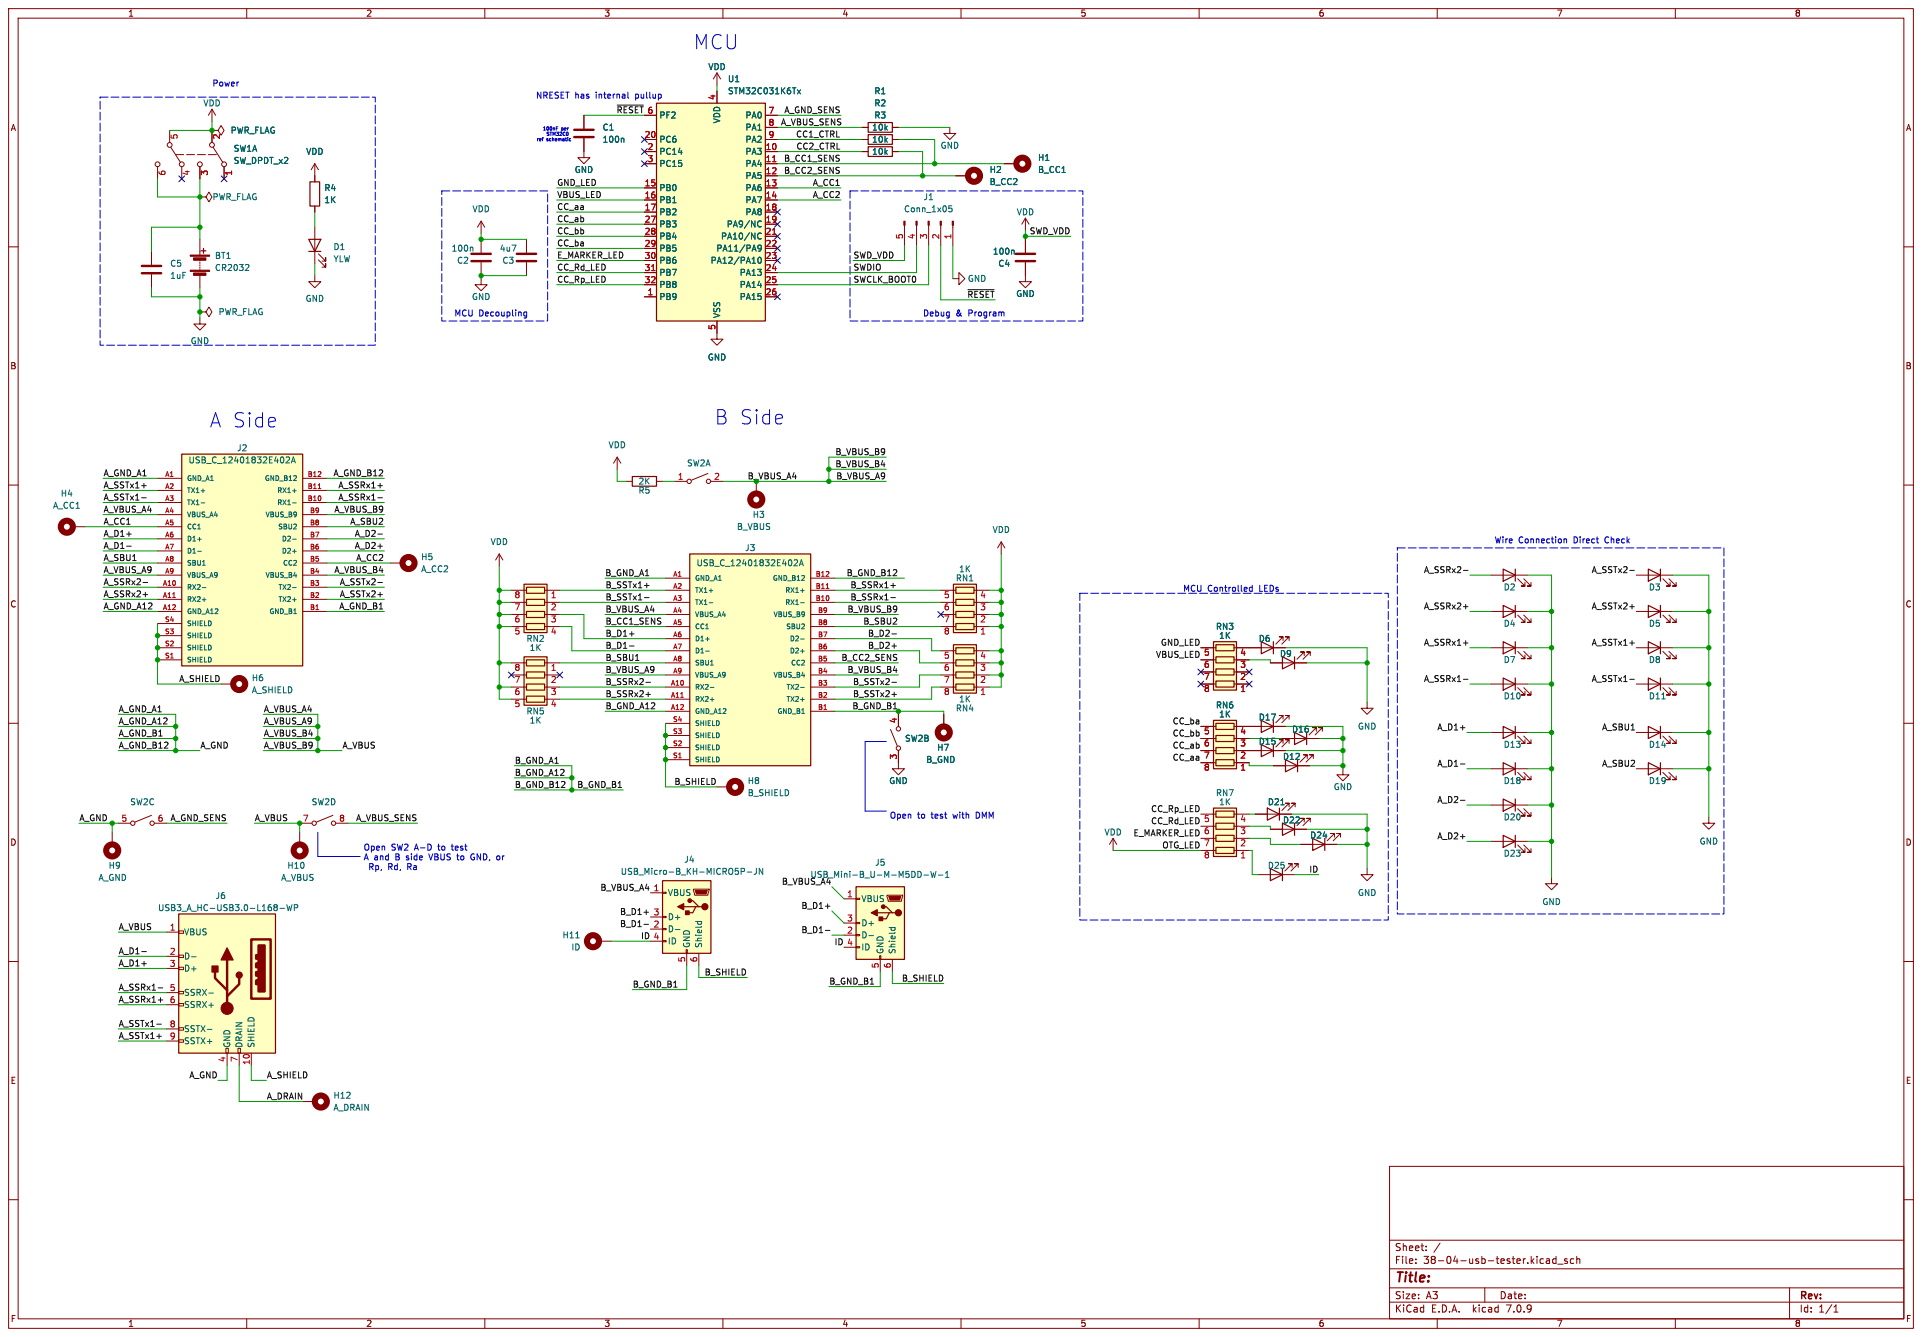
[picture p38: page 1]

Open to test with DMM

Id: 1/1 Title: File: 38-04-usb-tester.kicad_sch Sheet: /

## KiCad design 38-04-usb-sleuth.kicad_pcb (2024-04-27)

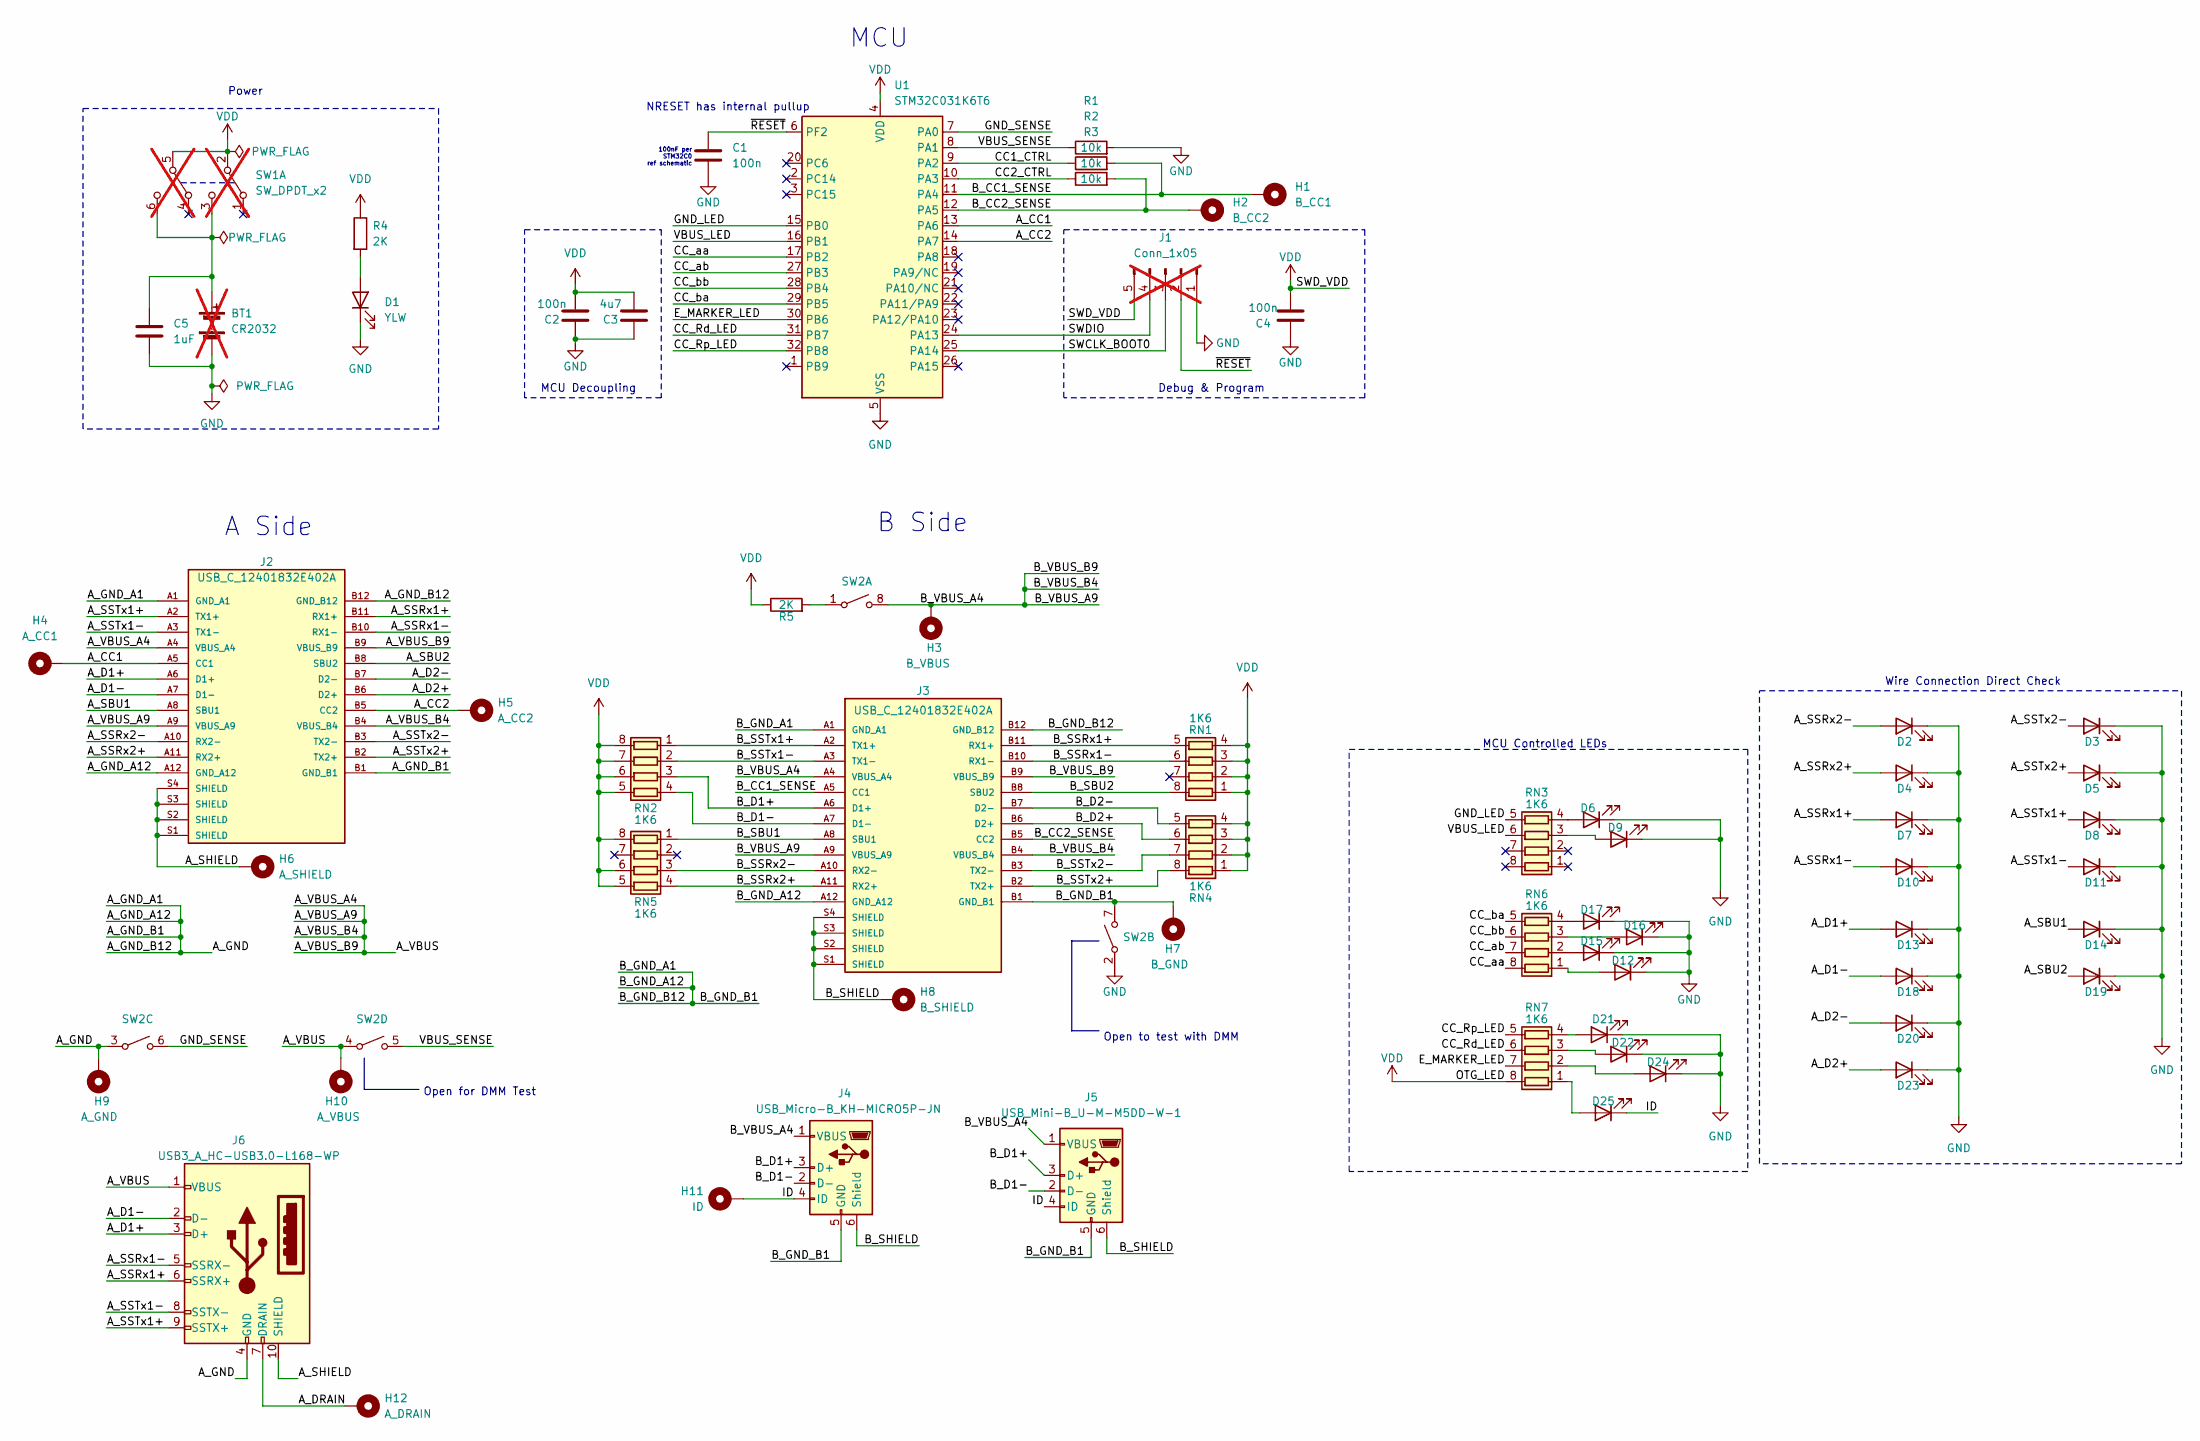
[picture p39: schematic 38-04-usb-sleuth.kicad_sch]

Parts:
BT1: CR2032; BatteryHolder_Keystone_103_1x20mm; LCSC Part # DNP; not fitted
C1, C2, C4: 100n; C_0402_1005Metric; LCSC Part # C1525
C3: 4u7; C_0805_2012Metric_Pad1.18x1.45mm_HandSolder; LCSC Part # C1779
C5: 1uF; C_0805_2012Metric_Pad1.18x1.45mm_HandSolder; LCSC Part # C28323
D1, D2, D3, D4, D5, D6, D7, D8, D9, D10, D11, D12, D13, D14, D15, D16, D17, D18, D19, D20, D21, D22, D23, D24, D25: YLW; LED_0805_2012Metric; LCSC Part # C2296
H1: B_CC1; Connector_Pad_Edge_Oval_5mm_Extended; LCSC Part # DNP
H2: B_CC2; Connector_Pad_Edge_Oval_5mm_Extended; LCSC Part # DNP
H3: B_VBUS; Connector_Pad_Edge_Oval_5mm_Extended; LCSC Part # DNP
H4: A_CC1; Connector_Pad_Edge_Oval_5mm_Extended; LCSC Part # DNP
H5: A_CC2; Connector_Pad_Edge_Oval_5mm_Extended; LCSC Part # DNP
H6: A_SHIELD; TestPoint_THTPad_D1.5mm_Drill0.7mm; LCSC Part # DNP
H7: B_GND; Connector_Pad_Edge_Oval_5mm_Extended; LCSC Part # DNP
H8: B_SHIELD; TestPoint_THTPad_D1.5mm_Drill0.7mm; LCSC Part # DNP
H9: A_GND; Connector_Pad_Edge_Oval_5mm_Extended; LCSC Part # DNP
H10: A_VBUS; Connector_Pad_Edge_Oval_5mm_Extended; LCSC Part # DNP
H11: ID; TestPoint_THTPad_D1.5mm_Drill0.7mm; LCSC Part # DNP
H12: A_DRAIN; TestPoint_THTPad_D1.5mm_Drill0.7mm; LCSC Part # DNP
J1: Conn_1x05; PinSocket_1x05_P2.54mm_Vertical; LCSC Part # DNP; not fitted
J2, J3: USB_C_12401832E402A; USB_C_Receptacle_Amphenol_12401832E402A; PARTREV X2; DigiKey_Part_Number 12401832E402ATR-ND
J4: USB_Micro-B_KH-MICRO5P-JN; USB_Micro-B_Kinghelm-KH-MICRO5P-JN; LCSC Part # C962222
J5: USB_Mini-B_U-M-M5DD-W-1; USB_Mini-B_Korean-Hroparts_U-M-M5DD-W-1_SMD-5-4MP; LCSC Part # C145778
J6: USB3_A_HC-USB3.0-L168-WP; USB3_A_Hong-Cheng_HC-USB3.0-L168-WP_THT-9-2MP_P2.0mm; LCSC Part # C7501850
R1, R2, R3: 10k; R_0805_2012Metric_Pad1.20x1.40mm_HandSolder; LCSC Part # C17414
R4, R5: 2K; R_0805_2012Metric_Pad1.20x1.40mm_HandSolder; LCSC Part # C17604
RN1, RN2, RN3, RN4, RN5, RN6, RN7: 1K6; R_Array_Concave_4x0402; LCSC Part # C728711
SW1: SW_DPDT_x2; SW_E-Switch_EG1271_SPDT; LCSC Part # DNP; not fitted
SW2: ZX-1.27BM-4PSMD; SW-DIP-4P_P1.27mm_SMD-2x4; LCSC Part # C5160896
U1: STM32C031K6T6; LQFP-32_7x7mm_P0.8mm; LCSC Part # C5456169

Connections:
/A_CC1: H4.1, J2.A5 (CC1), U1.13 (PA6)
/A_CC2: H5.1, J2.B5 (CC2), U1.14 (PA7)
/A_D1+: D13.2 (A), J2.A6 (D1+), J6.3 (D+)
/A_D1-: D18.2 (A), J2.A7 (D1-), J6.2 (D-)
/A_D2+: D23.2 (A), J2.B6 (D2+)
/A_D2-: D20.2 (A), J2.B7 (D2-)
/A_DRAIN: H12.1, J6.7 (DRAIN)
/A_GND: H9.1, J2.A1 (GND_A1), J2.A12 (GND_A12), J2.B1 (GND_B1), J2.B12 (GND_B12), J6.4 (GND), SW2.3
/A_GND_SENS: SW2.6, U1.7 (PA0)
/A_SBU1: D14.2 (A), J2.A8 (SBU1)
/A_SBU2: D19.2 (A), J2.B8 (SBU2)
/A_SHIELD: H6.1, J2.S1 (SHIELD), J2.S2 (SHIELD), J2.S3 (SHIELD), J2.S4 (SHIELD), J6.10 (SHIELD)
/A_SSRx1+: D7.2 (A), J2.B11 (RX1+), J6.6 (SSRX+)
/A_SSRx1-: D10.2 (A), J2.B10 (RX1-), J6.5 (SSRX-)
/A_SSRx2+: D4.2 (A), J2.A11 (RX2+)
/A_SSRx2-: D2.2 (A), J2.A10 (RX2-)
/A_SSTx1+: D8.2 (A), J2.A2 (TX1+), J6.9 (SSTX+)
/A_SSTx1-: D11.2 (A), J2.A3 (TX1-), J6.8 (SSTX-)
/A_SSTx2+: D5.2 (A), J2.B2 (TX2+)
/A_SSTx2-: D3.2 (A), J2.B3 (TX2-)
/A_VBUS: H10.1, J2.A4 (VBUS_A4), J2.A9 (VBUS_A9), J2.B4 (VBUS_B4), J2.B9 (VBUS_B9), J6.1 (VBUS), SW2.4
/A_VBUS_SENS: R1.1, SW2.5, U1.8 (PA1)
/B_CC1_SENS: H1.1, J3.A5 (CC1), R2.2, U1.11 (PA4)
/B_CC2_SENS: H2.1, J3.B5 (CC2), R3.2, U1.12 (PA5)
/B_D1+: J3.A6 (D1+), J4.3 (D+), J5.3 (D+), RN2.3 (R3.1)
/B_D1-: J3.A7 (D1-), J4.2 (D-), J5.2 (D-), RN2.4 (R4.1)
/B_D2+: J3.B6 (D2+), RN4.6 (R3.2)
/B_D2-: J3.B7 (D2-), RN4.5 (R4.2)
/B_GND_A1: H7.1, J3.A1 (GND_A1), J3.A12 (GND_A12), J3.B1 (GND_B1), J3.B12 (GND_B12), J4.5 (GND), J5.5 (GND), SW2.7
/B_SBU1: J3.A8 (SBU1), RN5.1 (R1.1)
/B_SBU2: J3.B8 (SBU2), RN1.8 (R1.2)
/B_SHIELD: H8.1, J3.S1 (SHIELD), J3.S2 (SHIELD), J3.S3 (SHIELD), J3.S4 (SHIELD), J4.6 (Shield), J5.6 (Shield)
/B_SSRx1+: J3.B11 (RX1+), RN1.5 (R4.2)
/B_SSRx1-: J3.B10 (RX1-), RN1.6 (R3.2)
/B_SSRx2+: J3.A11 (RX2+), RN5.4 (R4.1)
/B_SSRx2-: J3.A10 (RX2-), RN5.3 (R3.1)
/B_SSTx1+: J3.A2 (TX1+), RN2.1 (R1.1)
/B_SSTx1-: J3.A3 (TX1-), RN2.2 (R2.1)
/B_SSTx2+: J3.B2 (TX2+), RN4.8 (R1.2)
/B_SSTx2-: J3.B3 (TX2-), RN4.7 (R2.2)
/B_VBUS_A4: H3.1, J3.A4 (VBUS_A4), J3.A9 (VBUS_A9), J3.B4 (VBUS_B4), J3.B9 (VBUS_B9), J4.1 (VBUS), J5.1 (VBUS), SW2.8
/CC1_CTRL: R2.1, U1.9 (PA2)
/CC2_CTRL: R3.1, U1.10 (PA3)
/CC_Rd_LED: RN7.6 (R3.2), U1.31 (PB7)
/CC_Rp_LED: RN7.5 (R4.2), U1.32 (PB8)
/CC_aa: RN6.8 (R1.2), U1.17 (PB2)
/CC_ab: RN6.7 (R2.2), U1.27 (PB3)
/CC_ba: RN6.5 (R4.2), U1.29 (PB5)
/CC_bb: RN6.6 (R3.2), U1.28 (PB4)
/E_MARKER_LED: RN7.7 (R2.2), U1.30 (PB6)
/GND_LED: RN3.5 (R4.2), U1.15 (PB0)
/ID: D25.1 (K), H11.1, J4.4 (ID), J5.4 (ID)
/SWCLK_BOOT0: J1.3, U1.25 (PA14)
/SWDIO: J1.4, U1.24 (PA13)
/VBUS_LED: RN3.6 (R3.2), U1.16 (PB1)
/~RESET: C1.1, J1.2, U1.6 (PF2)
GND: BT1.2 (-), C1.2, C2.1, C3.1, C4.1, C5.2, D1.1 (K), D2.1 (K), D3.1 (K), D4.1 (K), D5.1 (K), D6.1 (K), D7.1 (K), D8.1 (K), D9.1 (K), D10.1 (K), D11.1 (K), D12.1 (K), D13.1 (K), D14.1 (K), D15.1 (K), D16.1 (K), D17.1 (K), D18.1 (K), D19.1 (K), D20.1 (K), D21.1 (K), D22.1 (K), D23.1 (K), D24.1 (K), J1.1, R1.2, SW2.2, U1.5 (VSS)
unnamed: BT1.1 (+), C5.1, SW1.3 (C), SW1.6 (C)
unnamed: D1.2 (A), R4.2
unnamed: D6.2 (A), RN3.4 (R4.1)
unnamed: D9.2 (A), RN3.3 (R3.1)
unnamed: D12.2 (A), RN6.1 (R1.1)
unnamed: D15.2 (A), RN6.2 (R2.1)
unnamed: D16.2 (A), RN6.3 (R3.1)
unnamed: D17.2 (A), RN6.4 (R4.1)
unnamed: D21.2 (A), RN7.4 (R4.1)
unnamed: D22.2 (A), RN7.3 (R3.1)
unnamed: D24.2 (A), RN7.2 (R2.1)
unnamed: D25.2 (A), RN7.1 (R1.1)
unnamed: R5.2, SW2.1
VCC: C2.2, C3.2, C4.2, J1.5, R4.1, R5.1, RN1.1 (R1.1), RN1.2 (R2.1), RN1.3 (R3.1), RN1.4 (R4.1), RN2.5 (R4.2), RN2.6 (R3.2), RN2.7 (R2.2), RN2.8 (R1.2), RN4.1 (R1.1), RN4.2 (R2.1), RN4.3 (R3.1), RN4.4 (R4.1), RN5.5 (R4.2), RN5.6 (R3.2), RN5.8 (R1.2), RN7.8 (R1.2), SW1.2 (B), SW1.5 (B), U1.4 (VDD)

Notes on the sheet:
MCU Controlled LEDs
Wire Connection Direct Check
MCU
100nF per STM32C0 ref schematic
NRESET has internal pullup
Power
Debug & Program
Open to test with DMM
A Side
Open for DMM Test
B Side
MCU Decoupling

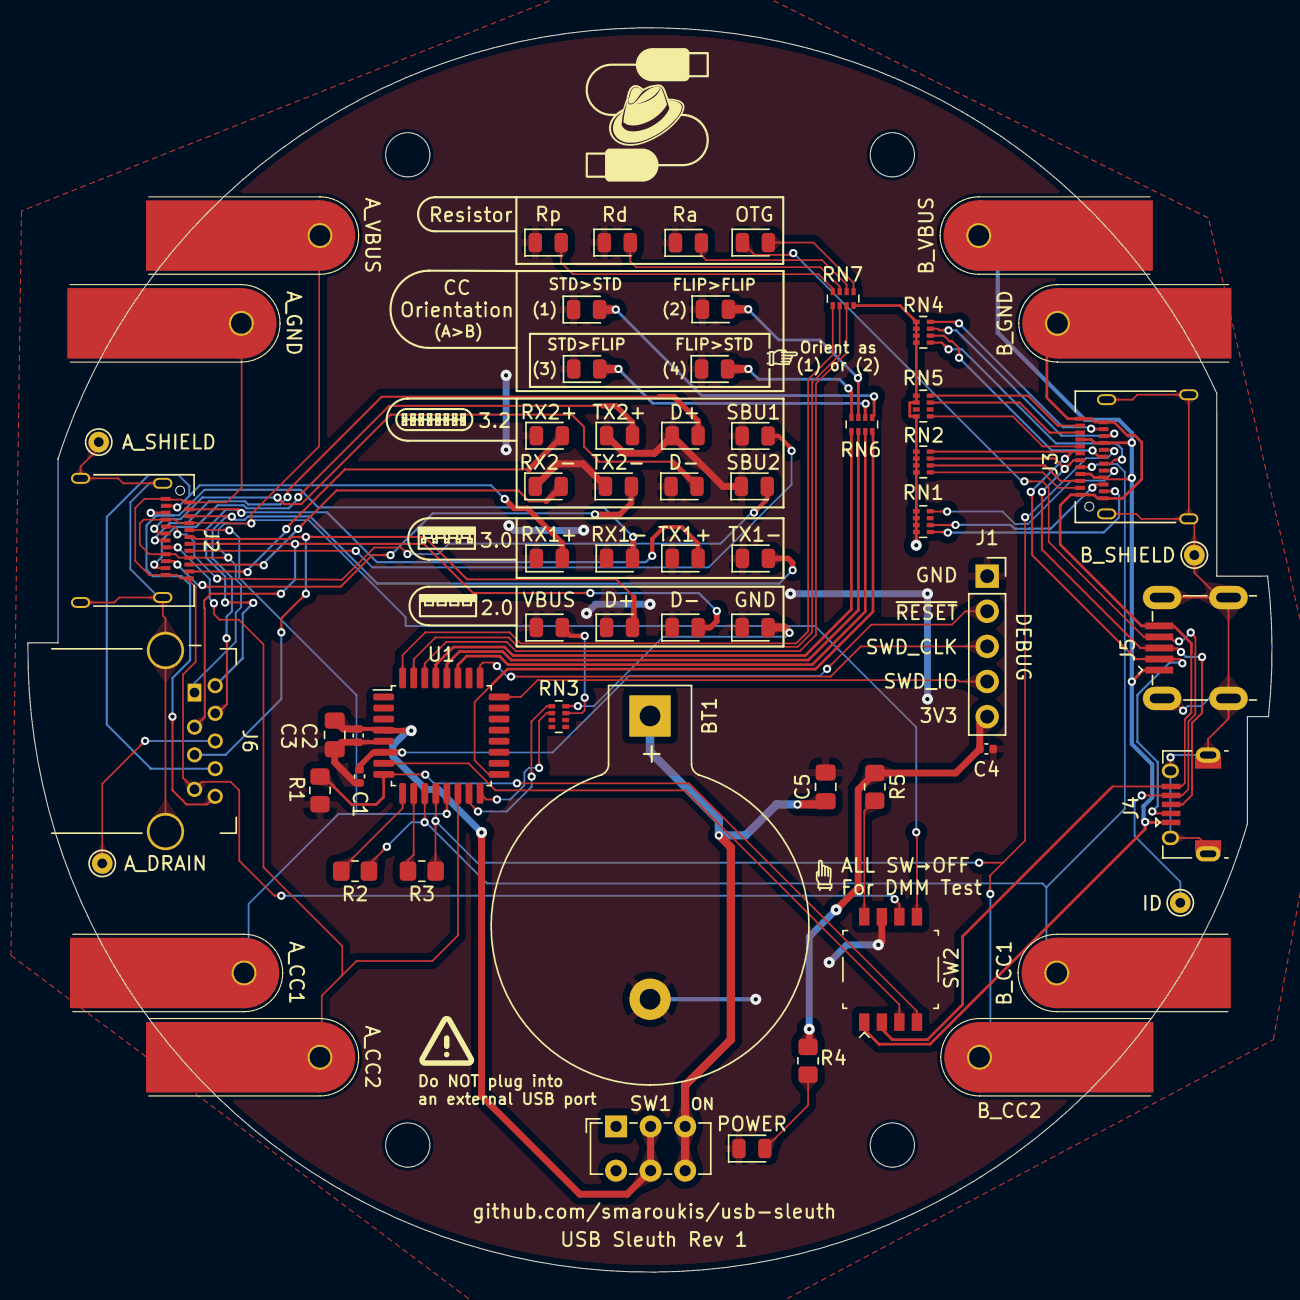
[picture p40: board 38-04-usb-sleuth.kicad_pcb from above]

Board: 2 copper layers, 90.0 x 90.0 mm, 64 parts (0 on the bottom side), 71 nets.

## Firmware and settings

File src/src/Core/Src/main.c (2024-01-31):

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
/* Includes ------------------------------------------------------------------*/
#include "main.h"

ADC_HandleTypeDef hadc1;

TIM_HandleTypeDef htim1;

/* USER CODE BEGIN PV */


// flags
uint8_t gnd_conn = 0;
uint8_t vbus_conn = 0;
uint8_t cc_conn_aa = 0;
uint8_t cc_conn_ab = 0;
uint8_t cc_conn_ba = 0;
uint8_t cc_conn_bb = 0;
uint8_t Rp_conn = 0;
uint8_t Rd_conn = 0;
uint8_t Ra_conn = 0;
uint16_t RP_THRESH = 300; // adjust for analog read
int analog_val1;
int analog_val2;

/* USER CODE END PV */

void SystemClock_Config(void);
static void MX_GPIO_Init(void);
static void MX_ADC1_Init(void);
static void MX_TIM1_Init(void);
/* USER CODE BEGIN 0 */

static void ADC_Select04(void) {
	  // Configure PA4
	  ADC_ChannelConfTypeDef sConfig = {0};

	  sConfig.Channel = ADC_CHANNEL_4;
	  sConfig.Rank = ADC_REGULAR_RANK_1;
	  sConfig.SamplingTime = ADC_SAMPLINGTIME_COMMON_1;
	  if (HAL_ADC_ConfigChannel(&hadc1, &sConfig) != HAL_OK)
	  {
	    Error_Handler();
	  }
}


static void ADC_Select05(void) {
	  // Configure PA5
	  ADC_ChannelConfTypeDef sConfig = {0};

	  sConfig.Channel = ADC_CHANNEL_5;
	  sConfig.Rank = ADC_REGULAR_RANK_1;
	  sConfig.SamplingTime = ADC_SAMPLINGTIME_COMMON_1;
	  if (HAL_ADC_ConfigChannel(&hadc1, &sConfig) != HAL_OK)
	  {
	    Error_Handler();
	  }
}

/* USER CODE END 0 */

/**
  * @brief  The application entry point.
  * @retval int
  */
int main(void)
{
  /* MCU Configuration--------------------------------------------------------*/

  /* Reset of all peripherals, Initializes the Flash interface and the Systick. */
  HAL_Init();

  /* Configure the system clock */
  SystemClock_Config();

  /* Initialize all configured peripherals */
  MX_GPIO_Init();
  MX_ADC1_Init();
  MX_TIM1_Init();
  /* USER CODE BEGIN 2 */

  // Note reconfigured GND_SENSE_Pin as Pullup in MX_GPIO_INIT() function above; all others are floating

  /* USER CODE END 2 */

  /* Infinite loop */
  /* USER CODE BEGIN WHILE */
  while (1)
  {
	  // ------ Section X - Drive LEDs based on previous loop -----------
	  // Port A: [8..0] is p CC_Rp_LED_Pin CC_Rd_LED_Pin ... VBUS_LED_Pin GND_LED_Pin ]
	  uint16_t led_mask = (
			  gnd_conn << 0 |
			  vbus_conn << 1 |
			  cc_conn_aa << 2 |
			  cc_conn_ab << 3 |
			  cc_conn_bb << 4 |
			  cc_conn_ba << 5 |
			  Ra_conn << 6 |
			  Rd_conn << 7 |
			  Rp_conn << 8
			  );

	  // set the outputs to the current value of the flags (note no mask)
	  GPIOB->ODR = ((uint16_t)led_mask); // set bits 0 to 8
	  //HAL_Delay(20);

	  // Reset flags for "single path" through code
	  gnd_conn = 0;
	  vbus_conn = 0;
	  cc_conn_aa = 0;
	  cc_conn_ab = 0;
	  cc_conn_ba = 0;
	  cc_conn_bb = 0;
	  Rp_conn = 0;
	  Rd_conn = 0;
	  Ra_conn = 0;

	  // ------ Section 1 - Testing VBUS Line ---------
	  // Requires: SW2A == Closed (VBUS_A4 → VDD via 2K)
	  // B_VBUS is pulled up to Vdd via 2K; A_VBUS_SENSE is pulled down via 10K; Vsense = 10K/12K = HIGH
	  if (HAL_GPIO_ReadPin(GPIOA, VBUS_SENSE_Pin) == GPIO_PIN_SET ) {
	    vbus_conn = 1;
	    HAL_Delay(300); // to allow plug to fully seat
	  }
	  else {
	    vbus_conn = 0;
	    // Now check for ground in the case that VBUS wire is damaged and we still want to test the others
	    // Note cable physical properties assures that ground connection is made before VBUS so no need for delay before reading GND_SENSE_Pin
	    if (HAL_GPIO_ReadPin(GPIOA, GND_SENSE_Pin) == GPIO_PIN_RESET) {
	    	HAL_Delay(300); // to let the other pins set since GND is first
	    	// proceed with other tests (note we set the gnd_conn flag below for passed test)
	    }
	    else {
	    	gnd_conn = 0;
	    	continue; // if VBUS_SENSE_Pin and GND_SENSE_Pin == 0 then restart the loop (flags will be reset after additional cycle)
	    }

	  }

	  // ------ Section 2 - Testing Ground Line ---------
	  // Requires: GND_SENSE pin as pullup input, SW2B == CLOSED (B_GND_B1 → GND)
	  // Check if the A side ground pin is pulled to ground (short), else HIGH via internal Rp
	  if (HAL_GPIO_ReadPin(GPIOA, GND_SENSE_Pin) == GPIO_PIN_RESET) {
		  gnd_conn = 1;

	  }
	  else {
		  gnd_conn = 0;
	  }

	  // ------ Section 3 - Test for USB C <> USB C --------
	  // Test Requires: A_CC1 == HIGH & A_CC2_Pin, CCx_CTRL_PIN == LOW
	  // Check B_CCx_Sense == A_CC1 with A_CC1 HIGH and all others LOW
	    GPIO_InitTypeDef GPIO_InitStruct = {0};

	    GPIO_InitStruct.Pin = A_CC1_Pin | A_CC2_Pin;
	    GPIO_InitStruct.Mode = GPIO_MODE_OUTPUT_PP;
	    GPIO_InitStruct.Pull = GPIO_NOPULL;
	    GPIO_InitStruct.Speed = GPIO_SPEED_FREQ_LOW;
	    HAL_GPIO_Init(GPIOA, &GPIO_InitStruct);
	    HAL_GPIO_WritePin(GPIOA, A_CC1_Pin | A_CC2_Pin, GPIO_PIN_SET); // A_CC1 & A_CC2 → HIGH for C<>C check

	    // Configure B_CCx_Sense pins as floating inputs
	    GPIO_InitStruct.Pin = B_CC1_SENSE_Pin | B_CC2_SENSE_Pin;
	    GPIO_InitStruct.Mode = GPIO_MODE_INPUT;
	    GPIO_InitStruct.Pull = GPIO_NOPULL;
	    HAL_GPIO_Init(GPIOA, &GPIO_InitStruct);
	    // Configure CCx_CTRL pins as output LOW
	    GPIO_InitStruct.Pin = (CC1_CTRL_Pin|CC2_CTRL_Pin);
	    GPIO_InitStruct.Mode = GPIO_MODE_OUTPUT_PP;
	    GPIO_InitStruct.Pull = GPIO_NOPULL;
	    HAL_GPIO_Init(GPIOA, &GPIO_InitStruct);
	    HAL_GPIO_WritePin(GPIOA, CC1_CTRL_Pin|CC2_CTRL_Pin, GPIO_PIN_RESET);

	    // "Entry Test" for C<>C With both A_CC1 & A_CC2 HIGH & B_CCx_CTRL LOW, one of B_CCx_SENSE should come HIGH
	    // Note this also works for the case that Rp is present since Rp is weak, the CTRL pulldown will override (since the pin won't be connected through to the A_CCx side)
	    if ( (HAL_GPIO_ReadPin(GPIOA, B_CC1_SENSE_Pin) == 1) || (HAL_GPIO_ReadPin(GPIOA, B_CC2_SENSE_Pin) == 1) ) {
		    // Test 3A with A_CC1 HIGH, STD>STD or STD>FLIP: if B_CCx_Sense is HIGH then it is connected to A_CC1
	    	// now pull A_CC2 LOW to test A_CC1 connection
	    	HAL_GPIO_WritePin(GPIOA, A_CC2_Pin, GPIO_PIN_RESET);
		    if (HAL_GPIO_ReadPin(GPIOA, B_CC1_SENSE_Pin) == 1) {
		    	cc_conn_aa = 1; // STD>STD is A_CC1→B_CC1
		    }
		    else {
		    	cc_conn_aa = 0;
		    	// Check for connection from A_CC1 to B_CC2
			    if (HAL_GPIO_ReadPin(GPIOA, B_CC2_SENSE_Pin) == 1) {
			    	cc_conn_ab = 1; // STD>FLIP is A_CC1→B_CC2
			    	// #here we never get past here?
			    }
			    else {
			    	cc_conn_ab = 0;
			    	// Could be due to A_CC1 connected to VCONN and pulled down via Active Cable, so check with A_CC2 HIGH
				    HAL_GPIO_WritePin(GPIOA, A_CC1_Pin, GPIO_PIN_RESET);
				    HAL_GPIO_WritePin(GPIOA, A_CC2_Pin, GPIO_PIN_SET);
				    // with A_CC2 HIGH check B_CC1_Sense (conn_ba)
				    if (HAL_GPIO_ReadPin(GPIOA, B_CC1_SENSE_Pin) == 1) {
				    	cc_conn_ba = 1; // A_CC2 → B_CC1 is Flip>Std or conn_ba
				    }
				    else {
				    	cc_conn_ba = 0;
				    	// with A_CC2 HIGH check B_CC2_Sense (conn_bb or Flip>Flip)
				    	if (HAL_GPIO_ReadPin(GPIOA, B_CC2_SENSE_Pin) == 1) {
				    		cc_conn_bb = 1;
				    	}
				    	else {
				    		cc_conn_bb = 0;
				    	}
				    }
			    }
		    }
	    	// end CC orientation test

		    // begin active cable test
		    // ------- Section 4: Test Active Cable (E Marker) ------
		    // If we set A_CC1 & A_CC2 as input pullup and read A_CCx, if one is LOW then there is Ra pulldown
		    // Note set the CCx CTRL pins to floating
		    // Requires: A_CCx as INPUT_PULLUP, CCx_CTRL as floating
		    GPIO_InitStruct.Pin = A_CC2_Pin | A_CC1_Pin;
		    GPIO_InitStruct.Mode = GPIO_MODE_INPUT;
		    GPIO_InitStruct.Pull = GPIO_PULLUP;
		    HAL_GPIO_Init(GPIOA, &GPIO_InitStruct);

		    GPIO_InitStruct.Pin = CC1_CTRL_Pin | CC2_CTRL_Pin;
			GPIO_InitStruct.Mode = GPIO_MODE_OUTPUT_OD;
			GPIO_InitStruct.Pull = GPIO_NOPULL;
			HAL_GPIO_Init(GPIOA, &GPIO_InitStruct);
			HAL_GPIO_WritePin(GPIOA, CC1_CTRL_Pin | CC2_CTRL_Pin, GPIO_PIN_SET); // open drain high is floating

			if ( cc_conn_aa || cc_conn_ab ) {
				// A_CC1 side is CC pin, so A_CC2 must be VCONN
				if ( (HAL_GPIO_ReadPin(GPIOA, A_CC2_Pin) == 0) ) {
					Ra_conn = 1;
				}
				else {
					Ra_conn = 0;
				}
			}
			else if ( cc_conn_ba || cc_conn_bb ) {
				// A_CC2 side is CC pin so A_CC1 must be VCONN
				if ( (HAL_GPIO_ReadPin(GPIOA, A_CC1_Pin) == 0) ) {
					Ra_conn = 1;
				}
				else {
					Ra_conn = 0;
				}
			}
			else {
					Ra_conn = 0;
				}

		    // end active cable test
	    }
	    else {
	    	// not a C<>C cable
	    	cc_conn_aa = 0;
	    	cc_conn_ab = 0;
	    	cc_conn_bb = 0;
	    	cc_conn_ba = 0;
	    }
	    // Reset Pins

	    // Test 5 & 6 - Type C to Type A or Type B Pullup or Pulldown

	    GPIO_InitStruct.Pin = A_CC2_Pin | A_CC1_Pin;
	    GPIO_InitStruct.Mode = GPIO_MODE_INPUT;
	    GPIO_InitStruct.Pull = GPIO_PULLUP;
	    HAL_GPIO_Init(GPIOA, &GPIO_InitStruct);
	    // Only test if not C<>C
	    if ( (cc_conn_aa || cc_conn_ab || cc_conn_ba || cc_conn_bb) == 0) {
	    	// Test 5 - Type C to B Pulldown 5K6
	    	// Result: If ACCx digital read is LOW then pulldown exists
	    	if ( (HAL_GPIO_ReadPin(GPIOA, A_CC1_Pin) == 0) || (HAL_GPIO_ReadPin(GPIOA, A_CC2_Pin) == 0) ) {
	    		Rd_conn = 1;
	    	}
	    	else {
	    		Rd_conn = 0;
	    	}

	    	// Test 6 - Type C to A Pullup Rp 56K - reqs ADC
	    	// Configure CCx_CTRL Pins as Output Low
		    GPIO_InitStruct.Pin = CC1_CTRL_Pin | CC2_CTRL_Pin;
		    GPIO_InitStruct.Mode = GPIO_MODE_OUTPUT_PP;
		    GPIO_InitStruct.Pull = GPIO_NOPULL;
		    HAL_GPIO_Init(GPIOA, &GPIO_InitStruct);
		    HAL_GPIO_WritePin(GPIOA, CC1_CTRL_Pin | CC2_CTRL_Pin, GPIO_PIN_RESET);

	    	// Configure B_CCx_Sense Pins as analog
	    	GPIO_InitStruct.Pin = B_CC1_SENSE_Pin | B_CC2_SENSE_Pin;
	    	GPIO_InitStruct.Mode = GPIO_MODE_ANALOG;
	    	GPIO_InitStruct.Pull = GPIO_NOPULL;
	    	HAL_GPIO_Init(GPIOA, &GPIO_InitStruct);

	    	// Configure ADC for B_CC1_Sense Pin PA4
			ADC_Select04();
			HAL_ADC_Start(&hadc1); // restart since we stopped it earlier
			// start, poll, assign
		    HAL_ADC_PollForConversion(&hadc1, 500U);
			analog_val1 = HAL_ADC_GetValue(&hadc1); // Example ADC reads with STLink 3.3V supply: LOW=130, Rp=500, HIGH=3000
			HAL_ADC_Stop(&hadc1);

			ADC_Select05();
			HAL_ADC_Start(&hadc1);
			// start, poll, assign
		    HAL_ADC_PollForConversion(&hadc1, 500U);
			analog_val2 = HAL_ADC_GetValue(&hadc1); // Example ADC reads with STLink 3.3V supply: LOW=130, Rp=500, HIGH=3000
			HAL_ADC_Stop(&hadc1);

			if ( (analog_val1 > RP_THRESH) || (analog_val2) > RP_THRESH ) {
				Rp_conn = 1;
			}
			else {
				Rp_conn = 0;
			}
    /* USER CODE END WHILE */

    /* USER CODE BEGIN 3 */
  }
  }
  /* USER CODE END 3 */
}

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


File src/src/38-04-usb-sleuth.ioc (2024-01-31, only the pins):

Mcu.UserName=STM32C031K6Tx
PA0.GPIO_Label=GND_SENSE
PA0.Signal=GPIO_Input
PA1.GPIO_Label=VBUS_SENSE
PA1.Signal=GPIO_Input
PA13.Signal=DEBUG_SWDIO
PA14-BOOT0.Signal=DEBUG_SWCLK
PA2.GPIO_Label=CC1_CTRL
PA2.Signal=GPIO_Output
PA3.GPIO_Label=CC2_CTRL
PA3.Signal=GPIO_Output
PA4.GPIO_Label=B_CC1_SENSE
PA4.Signal=ADC1_IN4
PA5.GPIO_Label=B_CC2_SENSE
PA5.Signal=ADC1_IN5
PA6.GPIO_Label=A_CC1
PA6.Signal=ADC1_IN6
PA7.GPIO_Label=A_CC2
PA7.Signal=ADC1_IN7
PA8.Signal=S_TIM1_CH1
PB0.GPIO_Label=GND_LED
PB0.Signal=GPIO_Output
PB1.GPIO_Label=VBUS_LED
PB1.Signal=GPIO_Output
PB2.GPIO_Label=CC_aa
PB2.Signal=GPIO_Output
PB3.GPIO_Label=CC_ab
PB3.Signal=GPIO_Output
PB4.GPIO_Label=CC_bb
PB4.Signal=GPIO_Output
PB5.GPIO_Label=CC_ba
PB5.Signal=GPIO_Output
PB6.GPIO_Label=E_MARKER_LED
PB6.Signal=GPIO_Output
PB7.GPIO_Label=CC_Rd_LED
PB7.Signal=GPIO_Output
PB8.GPIO_Label=CC_Rp_LED
PB8.Signal=GPIO_Output

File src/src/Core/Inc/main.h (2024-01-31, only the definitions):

#define GND_SENSE_Pin GPIO_PIN_0
#define GND_SENSE_GPIO_Port GPIOA
#define VBUS_SENSE_Pin GPIO_PIN_1
#define VBUS_SENSE_GPIO_Port GPIOA
#define CC1_CTRL_Pin GPIO_PIN_2
#define CC1_CTRL_GPIO_Port GPIOA
#define CC2_CTRL_Pin GPIO_PIN_3
#define CC2_CTRL_GPIO_Port GPIOA
#define B_CC1_SENSE_Pin GPIO_PIN_4
#define B_CC1_SENSE_GPIO_Port GPIOA
#define B_CC2_SENSE_Pin GPIO_PIN_5
#define B_CC2_SENSE_GPIO_Port GPIOA
#define A_CC1_Pin GPIO_PIN_6
#define A_CC1_GPIO_Port GPIOA
#define A_CC2_Pin GPIO_PIN_7
#define A_CC2_GPIO_Port GPIOA
#define GND_LED_Pin GPIO_PIN_0
#define GND_LED_GPIO_Port GPIOB
#define VBUS_LED_Pin GPIO_PIN_1
#define VBUS_LED_GPIO_Port GPIOB
#define CC_aa_Pin GPIO_PIN_2
#define CC_aa_GPIO_Port GPIOB
#define CC_ab_Pin GPIO_PIN_3
#define CC_ab_GPIO_Port GPIOB
#define CC_bb_Pin GPIO_PIN_4
#define CC_bb_GPIO_Port GPIOB
#define CC_ba_Pin GPIO_PIN_5
#define CC_ba_GPIO_Port GPIOB
#define E_MARKER_LED_Pin GPIO_PIN_6
#define E_MARKER_LED_GPIO_Port GPIOB
#define CC_Rd_LED_Pin GPIO_PIN_7
#define CC_Rd_LED_GPIO_Port GPIOB
#define CC_Rp_LED_Pin GPIO_PIN_8
#define CC_Rp_LED_GPIO_Port GPIOB

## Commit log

2023-11-15 first design
    [38-04-usb-tester.kicad_pcb, 38-04-usb-tester.kicad_sch]
2023-11-16 changed to usb port 24 pins
    [38-04-usb-tester.kicad_sch]
2023-11-16 direct led connections
    [38-04-usb-tester.kicad_sch]
2023-11-21 STM32 layout
    [38-04-usb-tester.kicad_sch]
2023-11-22 added through holes for testing and vbus-sense resistor
    [38-04-usb-tester.kicad_sch]
2023-11-27 code - gnd and vbus testing
2023-12-05 added new footprints, schematic edits
    [38-04-usb-tester.kicad_pcb, 38-04-usb-tester.kicad_sch]
2023-12-06 mini b and dip switch footprint and schems
    [38-04-usb-tester.kicad_pcb, 38-04-usb-tester.kicad_sch]
2023-12-07 edge pads and start of pcb layout
    [38-04-usb-tester.kicad_pcb, 38-04-usb-tester.kicad_sch]
2023-12-08 pcb layout - cleanup, DNP decisions
    [38-04-usb-tester.kicad_pcb, 38-04-usb-tester.kicad_sch]
2023-12-08 pre commit to importing template
    [38-04-usb-tester.kicad_pcb]
2023-12-08 added defaults for jlpcb, fixed usb schematics
    [38-04-usb-tester.kicad_pcb, 38-04-usb-tester.kicad_sch]
2023-12-11 started routing
    [38-04-usb-tester.kicad_pcb, 38-04-usb-tester.kicad_sch]
2023-12-11 layout of LHS usb
    [38-04-usb-tester.kicad_pcb]
2023-12-11 routing LEDs, started USB B side
    [38-04-usb-tester.kicad_pcb, 38-04-usb-tester.kicad_sch]
2023-12-12 via size change refactoring DRC errors
    [38-04-usb-tester.kicad_pcb, 38-04-usb-tester.kicad_sch]
2023-12-12 more layout DRC fixes
    [38-04-usb-tester.kicad_pcb, 38-04-usb-tester.kicad_sch]
2023-12-12 more layouts and DRC routing
    [38-04-usb-tester.kicad_pcb]
2023-12-12 board layouts and edge cut edits
    [38-04-usb-tester.kicad_pcb]
2023-12-13 moved usb footprints from board edge
    [38-04-usb-tester.kicad_pcb, 38-04-usb-tester.kicad_sch]
2023-12-14 renamed user symbol file
    [38-04-usb-tester.kicad_pcb, 38-04-usb-tester.kicad_sch]
2023-12-14 renamed libraries
    [38-04-usb-tester.kicad_pcb, 38-04-usb-tester.kicad_sch]
2023-12-14 added screenshot
    [38-04-usb-tester.kicad_pcb]
2023-12-14 added schematic
2023-12-15 edited schematic, added solder mask expansion, added more thermal reliefs
    [38-04-usb-tester.kicad_pcb, 38-04-usb-tester.kicad_sch]
2023-12-18 rev 1 sent for prod
    [38-04-usb-tester.kicad_pcb, 38-04-usb-tester.kicad_sch]
2023-12-18 cleanup docs and assets for rev1
    [bom.csv, designators.csv, positions.csv]
2023-12-19 correct SW2 footprint and symbol pin numbering
    [38-04-usb-tester.kicad_pcb, 38-04-usb-tester.kicad_sch]
2024-01-17 manufcatured rev 1
    [38-04-usb-tester.kicad_pcb]
2024-01-17 project name changes
    [38-04-usb-sleuth.kicad_pcb, 38-04-usb-sleuth.kicad_sch]
2024-01-24 touch main.c
    [38-04-usb-sleuth.kicad_sch]
2024-01-26 ADC first pass for Rp - works but not great
2024-01-26 adc continuous with user channel select functions
2024-01-26 ADC single shot single channel - for testing Rp flip/std
    [main.c]
2024-01-27 changed VBUS/GND sense test order to start fixing Rp/Rd testing bug for C<>C cable
    [main.c]
2024-01-27 fixed active Ra tests
    [main.c]
2024-01-27 fixed CC orientation for all 4 cases
    [main.c]
2024-01-27 active cable and cc configuration working together
2024-01-27 fixed Rd testing issue for C<>B
    [main.c]
2024-04-27 adding stm32ide project files and HAL Drivers
    [38-04-usb-sleuth-Edge_Cuts.dxf, 38-04-usb-sleuth.kicad_pcb]

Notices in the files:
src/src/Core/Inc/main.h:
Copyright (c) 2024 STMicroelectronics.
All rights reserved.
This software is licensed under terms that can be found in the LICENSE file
